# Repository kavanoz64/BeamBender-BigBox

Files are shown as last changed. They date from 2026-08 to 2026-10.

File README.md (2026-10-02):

# BeamBender BigBox

A digital scandoubler and HDMI output card for the **Amiga 4000**, with the **Amiga 2000 and 3000** supported as well.

The card plugs into the video slot, taps the digital RGB signals before they ever reach a DAC, and outputs clean **HDMI** with audio. No analogue stage, no capture artefacts, no flicker.

> This project is a big-box adaptation of [**jbilander/BeamBender**](https://github.com/jbilander/BeamBender), Jörgen Bilander's scandoubler for the Amiga 1200 (and 500). The original design's approach and much of its analogue and HDMI circuitry carry over directly. Jörgen has also provided hardware guidance throughout this redesign. All credit for the concept belongs upstream.

**Status: revision 0.3 hardware built and working on the Amiga 4000D, 4000T, 3000 and 2000 (ECS and OCS). Every Amiga monitor mode captured, including the A2024; interlaced modes deinterlaced motion-adaptively on both modules; integer and blended half-step scaling on both axes; with the Si5351C clock generator fitted, every output format on the i5 as well as the i9.** See [Status](#status) for detail.

---

## What's different from the A1200 original

The A1200 version clips onto the Lisa chip and connects to the main board via an FFC cable. Big-box Amigas expose the same signals on the video slot, so this version is a **single PCB with no cables**. It takes digital RGB, syncs and the pixel clock straight off the slot fingers, along with audio and power.

| | A1200 BeamBender | BeamBender BigBox |
|---|---|---|
| Signal source | Lisa chip (PLCC-84 clip) | Video slot |
| Boards | Two, joined by FFC | One |
| FPGA | Gowin GW1NR-9 (on-board) | Colorlight i5 or i9 module (SO-DIMM socket) |
| Video RAM | FPGA-internal | 8 MB 32-bit SDRAM on module |
| Audio in | 3.5 mm jack | Video slot, plus aux header and jack, mixed |
| Power | External connector | Slot |

---

## Hardware

**FPGA:** a [Colorlight i5 v7.0](https://github.com/wuxx/Colorlight-FPGA-Projects) module in a 200-pin DDR2 SO-DIMM socket (TE 1473149-4). The module carries a Lattice **ECP5 LFE5U-25F** (24k LUT), **8 MB of 32-bit SDRAM** for field storage, plus its own configuration flash and regulators.

Using a module rather than a bare FPGA is deliberate. The ECP5 only comes in BGA, and this design has a hard no-BGA-in-my-hands rule. A dead module is a socket swap, not a rework station. **SO-DIMM pin 41 is left unconnected** specifically so that the i5 and the i9 are interchangeable, since it is the one ball that differs between the two.

**The i9 (LFE5U-45F, 44k LUT, 4 PLLs) is the recommended module.** It is pin-compatible, it drops straight into the same socket, and the extra fabric and the two extra PLLs are doing real work: on a board without the clock generator below, the i9's PLLs are what clock the four VESA output formats, and it is the module with headroom for whatever comes next. Build with an i9 unless cost is the deciding factor.

The **i5 (LFE5U-25F)** remains fully supported as the cheaper option, with its own bitstream. On its own it covers the CEA formats plus 1920x1200, which is everything most people need for a television or a modern monitor; with the **Si5351C** fitted it has every format the i9 has. It is the fuller module, at 77 % of its logic now, so it is also the one that decides what fits.

**Clock generator:** an **Si5351C** (16-QFN) provides the pixel clocks the ECP5's PLLs cannot make from 27 MHz - 162 MHz for 1600x1200, 108 for 1280x1024, 65 for 1024x768 and 40 for 800x600 - on four inputs of the module. It was added to the revision 0.3 board as a rework and is part of the next revision. One firmware per module serves boards with and without it: at power-up the card measures the four pins, decides once which clocks are there, and offers each VESA format only while its clock is; an i9 falls back to its own PLL for a format whose clock is missing, an i5 drops to 1280x720. A one-output variant of the firmware (`-si1`) drives every VESA format from CLK0 alone, retuning the part over I²C at each format change, for a board that routes only that one output.

**Video out:** an **SiI9022A** HDMI transmitter fed 24-bit parallel RGB888 at up to 148.5 MHz. Bit-banged TMDS would not reach 1080p60 on a non-SERDES ECP5, so a real transmitter earns its place.

**Audio:** an **AK5720** 24-bit ADC digitises the audio and feeds I²S straight to the SiI9022A, bypassing the FPGA entirely. Ahead of it, an **OPA1692** inverting summing amplifier mixes the Amiga's line audio from the slot with an auxiliary input, so you can fold in another card's audio or an external source. The aux input appears on both an internal header and a switched 3.5 mm jack, where inserting a plug mechanically disconnects the header. The amplifier runs from the slot's +12 V through its own RC filter rather than the digital 5 V rail, and the ESD clamp on the external jack protects both entry points.

**HDMI +5 V:** HDMI requires the source to supply 5 V on pin 18, and plenty of DIY designs simply tie it to the board rail. That invites two failure modes: a shorted cable dragging your supply down, and cheap televisions pushing 5 V *back* into your system. A **TPS2553** load switch sits in that path instead, current-limited to a guaranteed minimum of 422 mA with reverse-current blocking, so neither can happen. Its enable and fault lines run to the FPGA, and the on-screen display reports the fault line.

**Level shifting:** two 74LVC16244 buffers translate the Amiga's 5 V logic to 3.3 V. The ECP5 is *not* 5 V tolerant, so these are mandatory rather than optional.

**Board:** 157.5 x 90 mm, 4-layer, with dedicated ground and 3V3 planes.

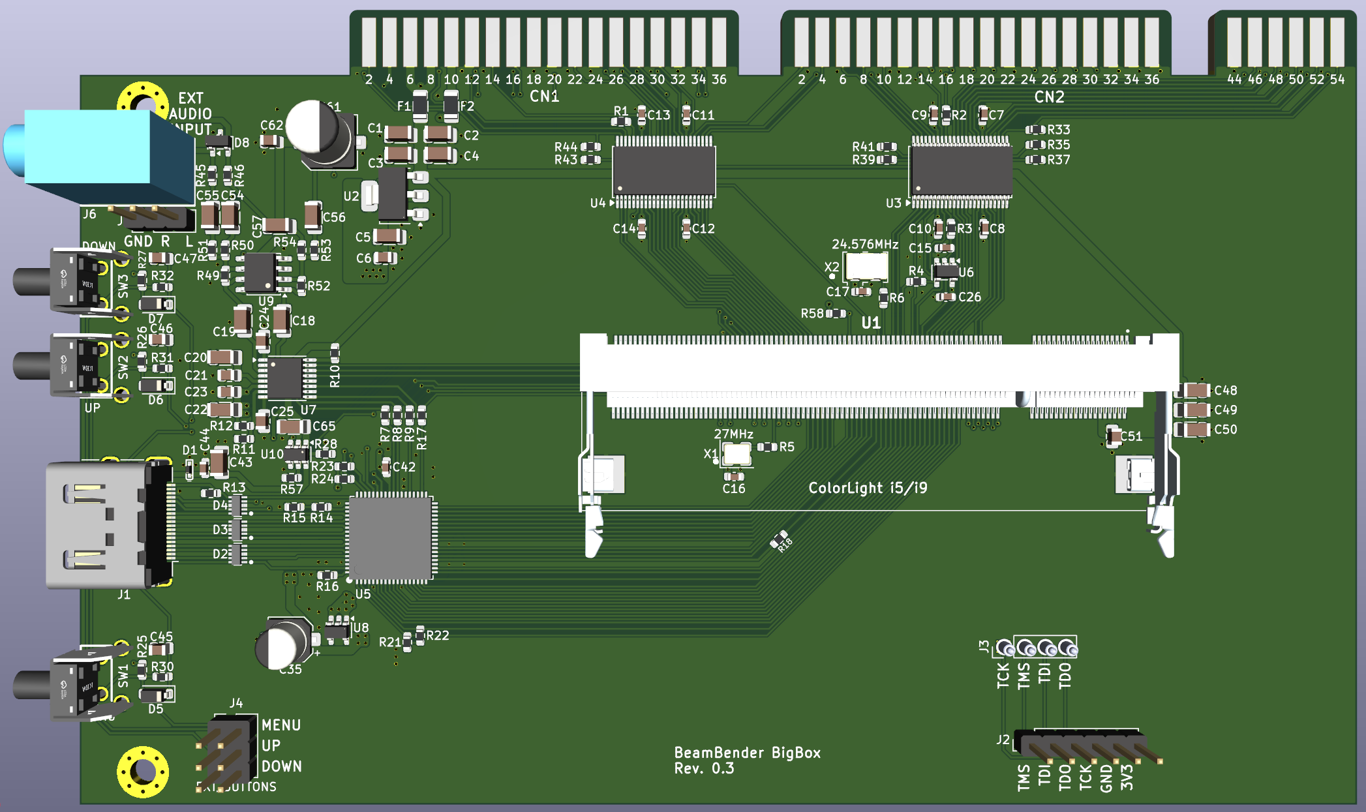
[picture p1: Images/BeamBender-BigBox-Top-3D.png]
PCB Top

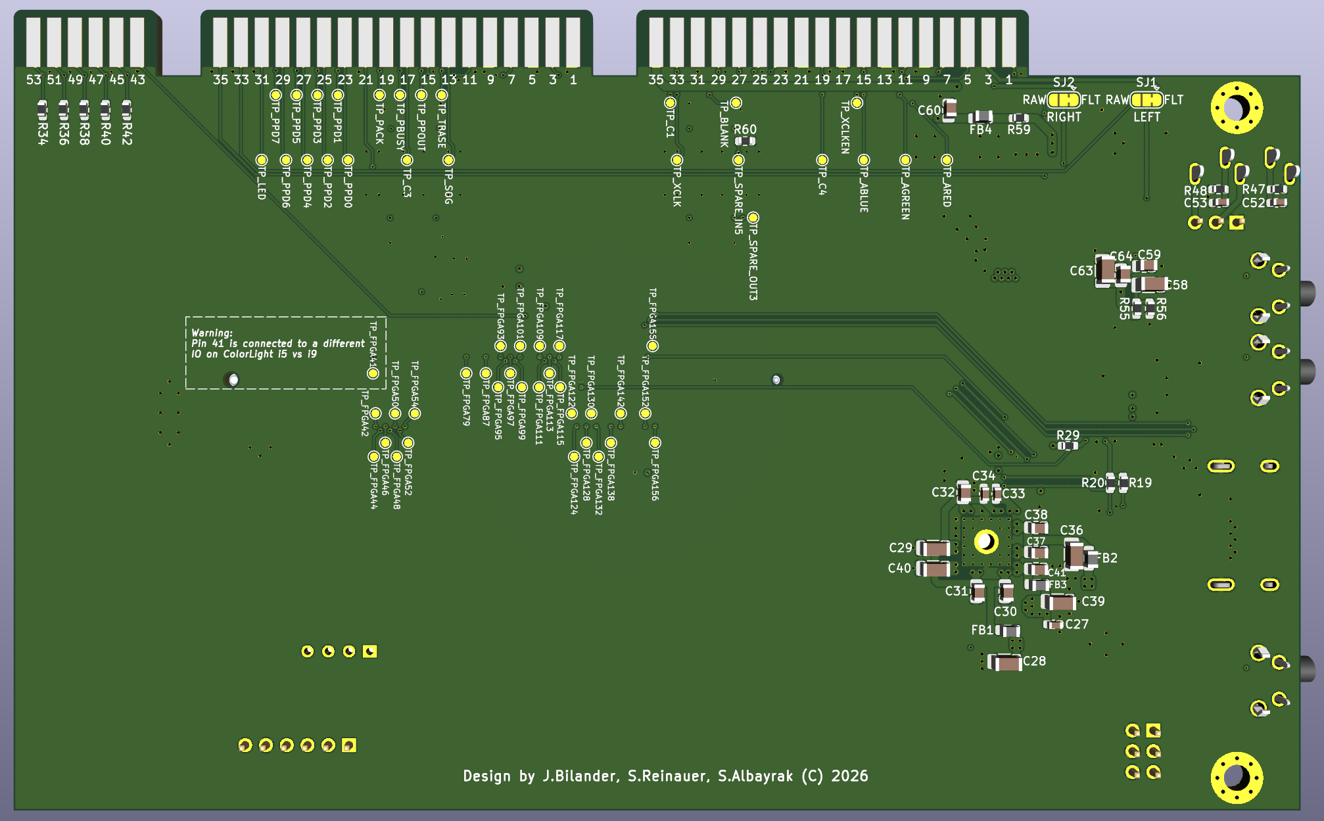
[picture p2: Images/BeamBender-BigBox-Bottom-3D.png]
PCB Bottom


### Where to buy the module

[Colorlight i5 + ext-board bundle on AliExpress](https://www.aliexpress.us/item/3256807602160285.html)

Buy the **module and the dev board together**. The BigBox card provides a JTAG header to program the module in place using an external programmer, but having the ext-board as well gives you a second, independent way to load and recover a bitstream, which may come handy.

---

## Clock architecture

Four clock inputs, on four dedicated ECP5 primary-clock pins.

| Clock | Source | ECP5 pin | PLL |
|---|---|---|---|
| **C28O**, 28.375 MHz PAL / 28.636 NTSC | Alice, via slot | 91 · `PCLKT2_1` | none, already the pixel clock |
| **VCDAC x2**, 14.19 MHz | Agnus/Alice CDAC, doubled on-board | 81 · `PCLKT3_1` | x2 to 28.375 MHz |
| **27 MHz** | on-board oscillator | 134 · `PCLKT7_1` | x5.5 to 148.5 MHz output |
| **24.576 MHz** | on-board oscillator | 89 · `PCLKT2_0` | none, audio MCLK reference |

Two details behind those choices:

**27 MHz is not arbitrary.** 148.5 MHz, the pixel clock for 1080p at both 50 and 60 Hz, is exactly 27 x 5.5, which the ECP5 PLL reaches cleanly. The module's own 25 MHz reference cannot produce it at any legal divider setting.

**The A2000 and A3000 have no 28 MHz clock on their video slots.** The fastest available is VCDAC at 7.09/7.16 MHz, which sits below the ECP5 PLL's 8 MHz input minimum. So an XOR gate and an RC delay double it to 14.19 MHz on-board, and the PLL takes it from there. Crude, cheap, and it adds no jitter of its own.

The two clocks that need PLLs sit on opposite die edges (banks 7 and 3), so each reaches its nearest PLL. That matters, because the LFE5U-25F only has two.

Both clock paths are confirmed on hardware: the A4000 runs from C28O, and the A3000 and A2000 run from the doubled VCDAC through the PLL. The card detects which is present and picks automatically, and the choice can be overridden from the menu. The Si5351C's four outputs come in on pins 81 (CLK0 162 MHz - the same pin as the doubled VCDAC on a board without the part; the firmware tells the two apart by frequency), 97 (CLK1 65), 142 (CLK2 108) and 138 (CLK3 40), and are measured by the firmware rather than assumed.

The card takes the slot's separate horizontal and vertical syncs. Composite sync alone is a build option (`--csync`), with the Sync Source row on the menu: it works on every mode including the AGA 31 kHz ones, but the separate syncs are the build that ships.

---

## Amiga 2000 / 3000 support

The pre-AGA video slot carries **12-bit color** (RGB444) rather than AGA's 24. Each nibble is replicated into both halves of an 8-bit channel, which is multiplication by 17. That maps 0 to 0 and 15 to 255 with no rounding error at any level.

Machine detection is passive. The AGA video slot extends the connector with pins 43 to 54, which don't exist at all on the A2000 and A3000. Pins 43 and 44 are ground, and 45 to 54 carry the extra color bits. A 10 kΩ pull-up on pin 43 therefore reads low on an A4000 and high everywhere else. The ten color lines on pins 45 to 54 get 100 kΩ pull-downs so their buffer inputs never float on a machine where those pins are absent.

The A3000 and the A2000, with OCS and with ECS chips, are all confirmed working.

---

## Programming

The module's JTAG pads aren't on the SO-DIMM edge, so four **spring-loaded pogo pins** contact them from below when the module is seated. A **1x6 JTAG header** runs in parallel for an external programmer. An FT232H or FT2232H dongle works directly with `openFPGALoader` or `ecpprog`.

Bitstreams can be loaded to SRAM for fast iteration, or written to the module's SPI flash through the same connection so the card boots on its own.

---

## Firmware

The gateware captures the Amiga's digital RGB into the module's SDRAM, scales it, and drives the SiI9022A.

**Prebuilt bitstreams are in [`Firmware/`](Firmware).** One file per module, named for the module and the firmware version. Load one and the card works; nothing else is needed. The AmigaOS tools that drive the card over its control link are in [`BBLink/`](BBLink), with their own README.

The firmware **sources are not published yet**. They will be, once the gateware reaches a maturity worth handing to other people. Until then the binaries are the deliverable, and the open items below are an honest account of what they do and do not do.

**Output formats.** One bitstream carries them all and the format is chosen from the menu:

| | i9 (recommended) | i5 | i5 with Si5351C |
|---|---|---|---|
| 720x576 / 720x480 | yes | yes | yes |
| 800x600 | yes | no | yes |
| 1024x768 | yes | no | yes |
| 1280x720 | yes | yes | yes |
| 1280x1024 | yes | no | yes |
| 1600x1200 | yes | no | yes |
| 1920x1080 | yes | yes | yes |
| 1920x1200 | yes | yes | yes |

All formats run at 50 or 60 Hz, following the Amiga automatically or forced from the menu. The format is chosen from a list rather than cycled, so the monitor re-locks once, on the one you asked for. A card with the Si5351C and no saved format comes up on 1280x1024, the format that shows a 512-line interlaced screen at exactly x2.

**Scaling.** The horizontal and vertical scales are chosen separately. **Auto** picks the largest integer that fits the format - PAL on 1080p is x2 by x3, a 512-line interlaced screen on 1280x1024 is x2 by x2 - and the picture is centred, with offsets from the menu. Forced scales add the **half steps, x1.5 to x5.5, blended**: each pair of source lines (or pixels) becomes 2k+1 rows (or columns) with the middle one the average of the two, so a PAL overscan screen of 288 lines fills 1008 of 1080p's rows at x3.5 with no uneven scanlines, and NTSC's 240 lines fill 1080 exactly at x4.5. Super-Hires is drawn on its own 1280 samples, never fewer columns than samples. Every number the menu shows is the screen's: a laced PAL screen reads 640x512, a Super-Hires one 1280 wide, the scale is per screen pixel and line, and the capture size times the scale is the output size. A format change, or a change of the screen being captured, puts both scales back on Auto. Scanline effect (two depths) and Super-Hires downsampling (sharp or soft, for the 720-wide formats) are settings; LoRes screens are stored one sample per pixel by default, so a 320-pixel screen reaches x6.

**Input.** Every mode the Amiga's monitor drivers produce: PAL and NTSC, Euro36, Euro72, Super72, DblPAL, DblNTSC and Multiscan, in LoRes, HiRes and Super-Hires, progressive and interlaced. The card recognises which monitor it is looking at from the line length and the lines per field, and keeps a settings set for each - and separate sets for the ECS and AGA chipsets, whose screens sit at different places on the line - so the geometry and sampling phase you set for one mode are there again the next time that mode appears. Picture position defaults come from a per-mode table of the Amiga's own placement (the A2000, A3000 and A4000 all measured), with manual Horizontal and Vertical Position on top. The Amiga's 28 input pins are registered in the pad cells, so the sampling edge does not move from build to build. Super-Hires is captured at full width, 1280 samples per line, one per output pixel rather than averaged down. Interlaced modes are **deinterlaced motion-adaptively, two samples at a time**: as each field is captured the card compares every pair of samples (one LoRes pixel, two HiRes ones) with the same pair of the previous field of the same parity, weaves the two fields wherever the picture is still and interpolates, from the neighbouring lines, only what moved - in either field - so a still Workbench stays as sharp as a weave, text keeps every one of its lines while the pointer passes over it, and a moving pointer or a scrolling window does not comb, however fast the pointer goes. Plain weave and bob are still there, chosen from the menu (Deinterlace = Adaptive, Weave or Bob), Display Info shows which of them the picture on screen actually has, and counts the changed pairs per field. Both modules do it, for every laced mode up to 768 samples a line, the 512-line DblPAL interlace included; Super-Hires interlace weaves plainly.

**The A2024** is supported as a 1024x1024 (PAL) or 1024x800 (NTSC) greyscale picture - BeamBender BigBox is the first Amiga scandoubler ever to display the A2024 modes. Commodore's monitor rebuilt its picture from four or six panels sent one per 15 kHz frame; the card does the same, assembling the panels in its frame buffer and showing the whole picture at 1:1 on 1280x1024 or 1080p. Both the 15Hz and 10Hz modes work, on PAL and NTSC.

**On-screen display.** A text menu on the card's three buttons covers output format and frequency, picture position, scale and offsets, capture width and height, scanline and picture effects, deinterlacing, menu size, position and background, the six OSD colours, source clock, sampling phase and calibration, plus Display Info, Monitor Info and Si5351 Info pages. Settings are written to the module's SPI flash and restored at power-up, and a record saved by an older firmware still loads.

**Monitor Info** reads the sink's EDID over the transmitter's DDC master and shows what the monitor actually claims to support, format by format, which is how you find out why a format is being refused.

**Hot plug.** The card watches the transmitter's hot-plug detect. Unplug the HDMI cable and plug it back in, or plug in a different monitor, and within about a second the transmitter is reconfigured for the new sink, the picture returns on its own, and the EDID is read again so Monitor Info describes the monitor that is there now. A cable that merely wobbles is ignored.

**Sampling calibration** sweeps the capture phase against a static picture and finds the centre of the eye. Needed because there is no fine phase shift available on the C28O path, and because the A3000's doubled clock has a narrower window than the A4000's.

**The Amiga control link** is three wires between test points already on the card - no new connector - giving a clocked full-duplex link to AmigaOS. The tools in [`BBLink/`](BBLink) drive it: `BBLink` (1.23) is a GadTools window with every setting, the live pages and the card's buttons; it backs the settings up to a human-readable text file and restores them, edits the OSD colours in a Palette-style editor, follows the sampling calibration through, and writes a report of what the card sees; `BBMode` tells the card which monitor the Amiga just switched to; `BBSurvey` walks every screen mode and logs what the card measured; `BBProbe` and `BBScreen` are the diagnostics; `BBLag` puts a field counter on the screen in digits big enough to film, for measuring the card's delay against the Amiga's own video. The wiring for the revision 0.3 board is in that README.

**Latency**, measured with BBLag and a 240 fps camera on a PAL HiRes screen: the picture on the card's HDMI monitor is between one and two fields (20 to 40 ms) behind the same picture on an analogue monitor, the HDMI monitor's own scaler included. One field of that is the frame buffer by design - the card shows the last field it has completely captured - and the rest drifts with the phase between the Amiga's field rate and the card's free-running output.

---

## Status

**The revision 0.3 board works.** Fabricated, assembled, and running on an **Amiga 4000D**, an **Amiga 4000T**, an **Amiga 3000** and an **Amiga 2000**. HDMI output, audio, the SDRAM frame buffer, the on-screen menu, settings in flash, every Amiga monitor mode including the A2024, the half-step scaling, the Si5351C clock generator (as a rework on this revision), and the Amiga link with its tools are all confirmed on hardware.

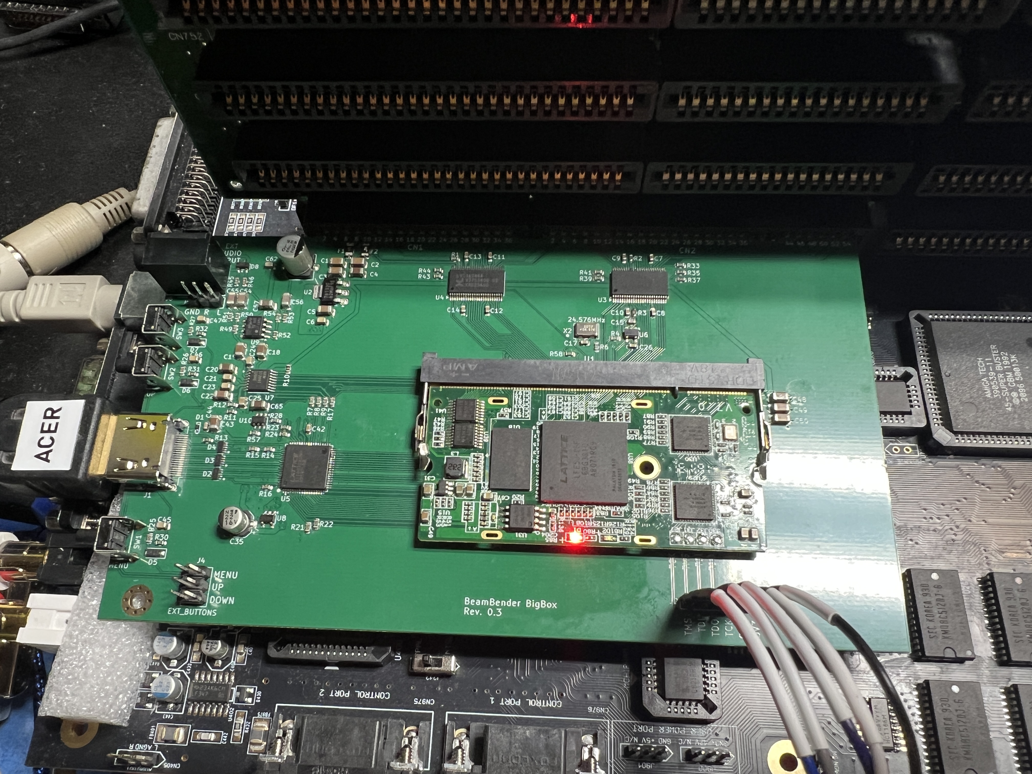
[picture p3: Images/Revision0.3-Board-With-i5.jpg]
Revision 0.3 board with an i5 module fitted


What is confirmed working:

- [x] First article fab and bring-up
- [x] HDMI output with audio, on multiple sinks
- [x] SDRAM frame buffer, full-width Super-Hires, interlace weave and bob
- [x] Motion-adaptive deinterlacing, on both modules
- [x] A4000D and A4000T (C28O path), A3000 and A2000 (doubled VCDAC path), OCS and ECS
- [x] Capture-phase calibration on real hardware, on both machine types
- [x] On-screen menu, settings saved to the module's SPI flash, one set per monitor mode
- [x] EDID read-back from the sink, shown format by format on Monitor Info
- [x] Hot plug: a replugged or swapped monitor comes back on its own, EDID re-read
- [x] Amiga control link and the AmigaOS tools: BBLink, BBMode, BBSurvey, BBProbe, BBScreen, BBLag
- [x] Latency measured: one to two fields to the HDMI monitor
- [x] i9 module support, with 800x600, 1024x768, 1280x1024 and 1600x1200
- [x] 1920x1200 on both modules
- [x] All the doubled-scan and productivity modes: DblPAL, DblNTSC, Super72, Euro36, Euro72, Multiscan
- [x] The A2024, 15Hz and 10Hz, PAL and NTSC, reassembled to the full 1024-line picture
- [x] The Si5351C clock generator: every output format on the i5, one firmware per module with or without the part
- [x] Blended half-step scaling, x1.5 to x5.5, both axes; Super-Hires on its own samples; the menu in screen pixels and lines
- [x] Composite sync on every mode, as a build option
- [x] OSD colours, settings backup and restore, a report, from BBLink

What is still open:

- [ ] Measure actual current on the 5 V and 3.3 V rails

### Next steps

**Hardware.** Measure the rails. The next board revision carries the Si5351C on the board and folds the Amiga link's three jumpers in as traces; one FPGA pin (the former BLANK input) is free.

**Firmware.** Publishing the sources.

---

## Building one

The Gerbers have not been published, but can be generated from the KiCad files here. The PCB is designed around **JLCPCB** fabrication and assembly, with part selection biased toward their basic library. The Colorlight module and the pogo pins are hand-fitted afterwards.

Fit an **i9** module unless cost rules it out. A finished board needs no toolchain: take the matching bitstream from [`Firmware/`](Firmware) and load it.

---

## Credits

- **[Jörgen Bilander](https://github.com/jbilander)**, original BeamBender design, and ongoing guidance on this adaptation
- **[Salih Albayrak (aka Kavanoz)](https://github.com/kavanoz64)**, hardware design and implementation for BigBox
- **[Stefan Reinauer](https://github.com/reinauer)**, FPGA programming
- **Claude AI** (Anthropic), design review, component selection, gateware and documentation
- **[wuxx](https://github.com/wuxx/Colorlight-FPGA-Projects)** and the Colorlight reverse-engineering community, for module pinouts and documentation that the vendor doesn't publish

## License

Please check the licensing of the upstream [BeamBender](https://github.com/jbilander/BeamBender) project before redistributing derived work.

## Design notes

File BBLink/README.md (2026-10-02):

# BeamBender BigBox — the Amiga tools

Five programs that talk to a BeamBender BigBox card from the Amiga it is
plugged into. Everything the card can do from its own on-screen display (OSD)
and its three buttons, you can do from here instead, with a keyboard and a
mouse and somewhere to read the numbers.

| | what it is for |
|---|---|
| [**BBLink**](#bblink) | the window. Every setting, the live pages, the card's buttons, and your settings backed up to a file. This is the one you will use. |
| [**BBMode**](#bbmode) | runs in the background and tells the card which monitor mode the Amiga just switched to. No longer needed - the card detects every mode by itself, reliably - but still here for anyone who wants the card told rather than left to measure. |
| [**BBSurvey**](#bbsurvey) | opens every screen mode the Amiga has, one after another, and logs what the card measures on each. |
| [**BBProbe**](#bbprobe) | for when nothing answers. It prints the raw bytes on the wire and squares up one line at a time so a meter or a scope can find the break. It also reads raw lines of the picture. |
| [**BBScreen**](#bbscreen) | opens one screen mode with a test pattern and runs a command in front of it. |
| [**BBLag**](#bblag) | a field counter in digits big enough to film, for measuring the card's lag against the Amiga's own video. |
| [**BBKeyCon**](#bbkeycon) | a commodity: Left Shift + Left Alt + a key presses the card's buttons and brings up its pages, from any screen. |

They share one link and take it only for the length of a single exchange, so
they can all run at the same time.

---

## Before anything will work

**The three link wires have to be fitted to the card.** On the revision 0.3
board they are three short wires and one resistor between test points that
are already there, plus one resistor to remove. See
[Wiring the link on a revision 0.3 board](#wiring-the-link-on-a-revision-03-board)
below. Without them the tools will say nobody answered, and they will be
right.

**Firmware and tool versions belong together.** BBLink shows the card's
firmware version in its title bar and its own under **About BBLink...**;
when the two firmware numbers differ, rebuild the tools against the
firmware you are running (see the About section below). A page or a row
the running firmware does not have is simply missing from the tool rather
than opened in the wrong place.

**Unplug any printer from the parallel port.** A printer holding the BUSY
line high blocks the card's side of the conversation. Nothing is damaged, it
simply cannot be read.

**AmigaOS 2.0 or later.** Nothing to install: everything these use is in ROM,
and `misc.resource`, which hands out the parallel port, is older than that.

## Installing

Unpack `bblink.lha` wherever you like — `SYS:Tools` is a reasonable home.

```
lha x bblink.lha
```

LhA keeps the protection bits, so the executable flag survives the trip and
none of the five needs `Protect +e`. The archive holds the five executables
and nothing else; this guide sits beside it.

## Wiring the link on a revision 0.3 board

The link is three signals from the Amiga's parallel port, which reach the
video slot on CN622: **PPOUT** (the clock, Amiga to card), **PSEL** (data,
Amiga to card) and **PBUSY** (data, card to Amiga). PSEL is already routed
on the board. The other two are made with wire on the test points, as the
photo shows:

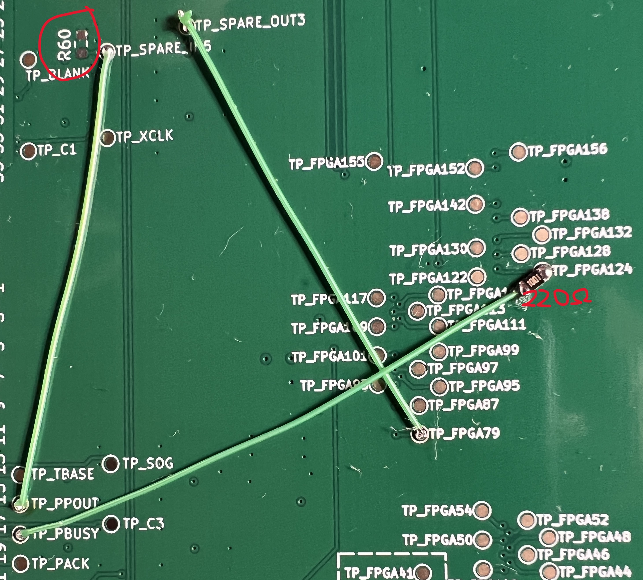
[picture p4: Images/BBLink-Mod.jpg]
The link wiring on a revision 0.3 board


1. **TP_PPOUT to TP_SPARE_IN5** - a wire. PPOUT goes in through a spare
   channel of the 5 V to 3.3 V buffer.
2. **TP_SPARE_OUT3 to TP_FPGA79** - a wire. The buffered PPOUT reaches the
   FPGA.
3. **TP_FPGA124 to TP_PBUSY through a 220 Ω resistor** (200 Ω is fine too).
   The card's reply. The FPGA only ever pulls this line low; the Amiga's
   own pull-up makes the high, so no 3.3 V is ever driven onto the 5 V net.
4. **Remove R60**, the 0 Ω link circled in the photo, which ties SPARE_IN5
   to ground. Leaving it fitted holds the clock input low and nothing will
   ever answer.

Four solder joints and one part lifted. Nothing else on the board changes,
and the card works exactly as before with the wires fitted and no tool
running.

---

# BBLink

Double-click it, or run it from a Shell. A window opens on the default public
screen with the card's firmware version in the title bar:

```
BBLink 1.23  2026-09-30.07 i9
```

**That version is the CARD's**, read over the link. The tool's own is under
**About BBLink...** in the Project menu (right mouse button):

```
BBLink 1.23  for firmware 2026-09-30.07
Oct  1 2026  18:30:00

Card: 2026-09-30.06 i9
```

If those two firmware numbers differ, the tool was built against tables from
another firmware. It still runs, but a setting that moved between those two
versions will be in the wrong place, so rebuild it against the firmware you
are running.

The second line is when that binary was compiled, and it is the one to look
at when a rebuild does not seem to have taken. It is fixed at compile time,
so it cannot be stale, and it settles at a glance whether the program in
front of you is the one you just built or an older copy still sitting on
the Amiga. The About BUTTON on the main screen is the card's own About page,
which is about the card.

## The main screen

Top to bottom:

- **Output Format**, **Output Frequency**, **Status Lines** and **Menu
  Position**, the settings you change most often. Output Format drops a
  list under its button - one row a format, the current one marked `>`:
  click the format you want and the card switches
  to it, or click anywhere else to leave it. The list is in ascending
  order and shows 720x480 or 720x576 according to the frequency the card
  is on. The other three are cycle gadgets: a click steps to the next
  value. Status Lines turns the two information lines at the top and
  bottom of the picture off and on; Menu Position moves the card's menu
  block through the centre and the four corners of the picture, so it can
  be put where it covers nothing you are looking at.
- **Display Info** | **Input Sampling**
- **Monitor Info** | **Output Geometry**
- **Settings** | **Load Settings** | **Save Settings**
- **Reset to Defaults** | **Report** | **About**
- **Refresh Rate**, with its own gadget: `Off`, `1 second`, `2 seconds`,
  `5 seconds`.
- **MENU** | **MENU Long**
- **UP** | **UP Long**
- **DOWN** | **DOWN Long**

A button that opens another page takes you there; **Go Back <<** at the
bottom of each page brings you home. The line along the bottom of the window
is where the tool tells you what just happened.

## Output Geometry

Five rows, one axis at a time: **Horizontal Offset** and **Horizontal
Scale**, then **Vertical Offset** and **Vertical Scale**. The offsets move
the finished picture inside the frame your monitor is given; the scales
decide how big it is.

Each scale is `Auto` or `x1` to `x6` in half steps (`x1.5`, `x2.5` ... the
half step draws every second column or row as the blend of its two
neighbours): how many output columns each screen pixel gets, or how many
output rows each screen line. `Auto` picks what the card has always picked
- horizontally the multiplier that fills the 4:3 box, vertically the largest
that fits the active area - and is right almost always. Force one when you want something else: smaller, to make
room for **overscan** (capture more with Capture Width or Capture Height and
it grows into the space instead of pushing the scale down a step), or
larger, to fill a 16:9 screen edge to edge with a picture that was never
that shape.

**A scale that does not fit is skipped.** The card's own cycle only stops on
the scales its current output format has room for, given the size of the
capture: 320 columns on 1280x1024 offer `Auto, x1 ... x4` and skip anything
above. From here the gadget still lists every value, and one the card
cannot use is refused with a message rather than taken. Display Info's
`Scale` row (`2x4` is horizontal x vertical, `1.5x3.5` with half steps)
shows what is actually in force, and the rows read the same: a forced scale
the card cannot use on the screen it is looking at reads `Auto` until that
screen is back.

**Every number is the screen's.** Capture Size is the width in the screen's
own pixels (640 HiRes, 1280 Super-Hires) and the height in its lines (512
for an interlaced PAL screen, 1024 for the A2024), the Capture Height row
counts the same lines (stepping by two on an interlaced screen), and the
scale is per screen pixel and per screen line, so Capture Size times Scale
is what goes to the output. On a Super-Hires screen every sample is drawn,
so the horizontal cycle offers `x1, x1.5, x2 ...` and never fewer columns
than samples; the one fraction below 1, `x0.5`, appears only where 1280
samples have to fit 640 columns (the SD formats).

The offsets and scales are saved per output format and frequency; the
positions, sampling phase and capture size per monitor mode. Changing the
output format puts both scales of the new format back on `Auto` ("no
surprises"); the flash keeps what was saved until the next Save Settings.

## Changing a setting

Every setting the card has is on one of the pages, one gadget per setting.
Settings that pick from a few values get a cycle gadget, Output Format a
drop-down list, and settings that are numbers get `[-] value [+]`.

A setting the card has greyed out in the current output format is **ghosted**
here too. A gadget you cannot click says the same thing as `N/A` and cannot
be clicked by mistake.

When you change something, the card's own menu appears on the monitor and
moves for a few milliseconds while the card walks to that setting, then it is
put back exactly where it was. That flicker is normal and is the card being
driven, not a fault.

**Nothing is kept until you press Save Settings.** Everything you change is
live immediately and lost at the next power cycle unless you save it.

## The live pages

**Display Info**, **Monitor Info** and **About** are the card's own pages,
row for row. Each is a screen of its own with a **Go Back <<** at the bottom,
so there is nothing else on screen while you are reading one.

A page is read the moment you open it, and then re-read on the timer you set
with **Refresh Rate** back on the main screen. Set that to `Off` and a page is
read once, when you open it, and then left alone until you leave and come
back.

Display Info carries one row the card cannot draw, because it is about the
**Amiga's** end of the link: how many exchanges have been retried and how
many were given up on. A link that works but retries constantly is a wiring
problem, and this is where you see it.

## The card's buttons

**MENU**, **UP** and **DOWN**, and a long press of each. Six gadgets rather
than three that you hold down, because a window cannot time a click reliably
and guessing at it would be worse than saying plainly what each one does.

## Load, Save, Defaults, Calibrate

- **Save Settings** writes everything to the card's flash. It survives a power
  cycle and a fresh bitstream, because it lives in a corner of the flash that
  programming the card does not touch.
- **Load Settings** reads the flash back and throws away everything changed
  since the last save. The row says `Loaded`, or `Failed` when there is no
  usable record in the flash - after the rescue erase, say - and in that case
  nothing at all is changed.
- **Reset to Defaults** puts every setting back and does **not** save. Press
  Save Settings afterwards if that is what you want kept.
- **Calibrate Sampling**, on the Input Sampling page, sweeps the sampling
  phase on the card (a few seconds, the card's own screen showing the
  scores) and then waits for a verdict. From BBLink 1.22 the tool follows
  it: while the card waits, the Calibrate Sampling button becomes
  **Accept | Cancel**, every other row and button on the page is greyed,
  and the **-** and **+** of Sampling Phase walk the card's selection
  through the twenty measured points with the picture showing each.
  Accept keeps the phase shown, Cancel puts back the one in use before the
  sweep; the page is restored either way, and also when the verdict is
  given with the card's own buttons.

## Report

**Report** writes `RAM:BBLink.txt`: the firmware version, every page, every
setting and the link's retry counters. This is the one to press before
describing a problem to anybody.

## Backup and Restore Settings

Both are in the **Project** menu, on the right mouse button, with **OSD
Colours**, **About BBLink** and **Quit** under them. Each opens the standard file requester (asl.library;
without it the file is `PROGDIR:BeamBender.settings` and the status line
says so).

**Backup Settings...** reads every setting off the card and writes it as a
text file you can read and edit:

```
# BeamBender BigBox settings
# From a BigBox i9 running 2026-09-30.07, by BBLink 1.23
# The live settings: what Save Settings would have written.

[General]
Output Format = 1920x1080
Output Frequency = Auto
Status Lines = Shown
Menu Position = Center
Deinterlace = Adaptive
...

[Input PAL]
Horizontal Position = 413
Vertical Position = 40
Vertical Half Line = No
Sampling Phase = 102
Pixel Phase = 0
Capture Width = 640
Capture Height = 256   # lines per field: an interlaced screen shows twice this

[Output 1920x1080 50Hz]
Horizontal Offset = 0
Vertical Offset = 0
Horizontal Scale = Auto
Vertical Scale = Auto
```

The scales are under the OUTPUT they belong to: a scale is an answer to
how big the picture should be on a given output, and the card keeps one
pair per output format alongside the offsets. The file keeps each SET'S
own units, since one set serves both the progressive and the interlaced
screens of its standard: `Capture Height` is lines per field (256 where
the window shows 512 on an interlaced screen), and `Horizontal Scale` the
value on the 640-column grid (x2 where a Super-Hires screen shows x1). The
report and the window show the screen's numbers. BBLink 1.23 or later is
needed for a file with half-step scales: 1.22 wrote them as `Auto`.

The words are the card's own: what a row shows on the monitor is what the
file says. It is the **live** settings that are written, including anything
changed and not yet saved; if you want exactly what is in the flash, press
Load Settings first.

**Restore Settings...** reads such a file and sends it to the card. Names are
matched, not positions, so a file from an older firmware puts back everything
it has and leaves the rest as the card has it; a name the card does not know,
or a value it cannot take, is counted and shown before anything is sent, and
you can stop there. The card checks the whole record before it applies any
of it, so a file it will not accept changes nothing. Afterwards the tool
reads the settings back and says whether they match - and then asks whether
to **Save Settings**, because a restore lives only until the next power
cycle until you do.

This is also the way to carry settings across a firmware update that changes
the record format: back up before, restore after, and the positions and
sampling phases you spent an evening on are back without a button pressed.

## OSD Colours

**OSD Colours...** in the Project menu (BBLink 1.21, firmware 2026-09-28.02
or later; spelt "Colors" unless the OS's locale says the United Kingdom)
is a small Palette Prefs: a list of the six colours the card
draws its menu in - the **Bands** (the bars at the top and bottom of the
block), the **Highlight** bar under the selected row, **Labels**,
**Values**, the **Shadow** under the text, and the menu **Background** (the
colour the picture is dimmed towards at the Menu Background levels
between 0 and 100 %, and the solid colour at 100 %) - with a swatch of
the selected one under the list, Red / Green / Blue sliders with their
numbers, the hex, and on Workbench 3.0 or later the colour wheel with its
brightness slider (the sliders alone on 2.x). Text on the highlight bar
is drawn in the shadow's colour; the alert red stays red. **Apply** sends
the six to the card, which draws them at once; **Save** applies and then
writes the card's flash, as Save Settings does; **Defaults** puts the
built-in colours back in the list (FFD000, FFD000, B0B0B0, FFFFFF,
000000, 000000) for the next Apply; **Cancel** closes the window. The
colours are part of the settings record, so a backup carries them under
`[OSD Colours]` and a restore puts them back. **Quit** in the same menu
closes the tool, as the window's close gadget does.

### From a Shell

Both work without the window, for scripts and for a backup before every
firmware update:

```
BBLink BACKUP <file>            the live settings to a file
BBLink RESTORE <file>           a file to the card; not saved to the flash
BBLink RESTOREANDSAVE <file>    a file to the card AND into its flash
BBLink ... QUIET                say nothing; the return code is the answer
```

The keywords are AmigaDOS ones, so `BBLink backup SYS:bb.settings` and
`BBLink BACKUP=SYS:bb.settings` are the same command. A restore from the
shell has nobody to ask, so a name the card does not know or a value it
cannot take is reported and the rest is sent. The return code is 0 when
everything was done, 5 (WARN) when the restore went in but something in the
file was skipped, and 20 (FAIL) when nothing was changed: the file could not
be read, the card refused the record, or the save did not verify. A script
can test it:

```
BBLink RESTOREANDSAVE SYS:bb.settings QUIET
IF WARN
  Echo "Some of the file was not restored"
ENDIF
```

---

# BBMode

**Run it from a Shell**, or put it in your `S:User-Startup`.

```
BBMode              follow the front screen until Ctrl-C
BBMode QUIET        the same, silently
BBMode ONCE         set the card to match the screen now, then exit
BBMode KEEP         do not put the card back on Auto on the way out
BBMode DELAY=n      how often to look, in ticks (default 25, half a second)
```

It prints one line every time the screen mode changes and nothing at all in
between:

```
PAL:High Res             -> PAL        ok
DBLPAL:High Res Laced    -> DBLPAL     ok
SUPER72:High Res         -> SUPER72    ok
```

`ok` means the card **read back** in that mode, not merely that a message was
sent.

## What it is for

**You do not need it.** The card works out which monitor it is looking at
from the line length and the lines per field, and the A2024 from its
colour signature, and it does so reliably for every mode the Amiga has;
that is what **Auto** does, and Auto is the right setting. BBMode exists
for the one thing a measurement cannot do: the Amiga chose the mode, so it
knows which monitor it is about to produce before the first line is drawn,
and BBMode passes that on, so the card need not wait the few frames the
measurement takes to settle.

It changes nothing else: not the sampling phase, not the positions, not the
capture height. Those are per-monitor settings the card already keeps and
reloads by itself. This only says **which monitor**.

## In your startup

```
Run >NIL: <NIL: BBMode QUIET
```

`Break <task>` stops it, exactly as Ctrl-C does from a Shell. Started from
Workbench it goes quiet by itself, since there is nowhere for it to print.

## On the way out it puts the card back on Auto

Unless you give it `KEEP`. A card left pinned by a program that is no longer
running will sample the next 15 kHz mode with 29 kHz settings, and nobody ever
connects that to something they stopped an hour ago.

## If a mode prints "monitor not in the table"

```
FOO:Something            -> Auto       (monitor not in the table)
```

The card is left on Auto, which is exactly where it would have been without
BBMode, so nothing is worse. Send that line on and the monitor can be added.
BBMode matches on the monitor name, the part before the colon, and knows
PAL, NTSC, EURO (36Hz and 72Hz told apart by the mode name), A2024 (PAL or
NTSC by the standard the machine booted in), SUPER72, DBLPAL, DBLNTSC,
MULTISCAN, VGA and PRODUCTIVITY (the last two as Multiscan). A plain mode
with no monitor name follows the boot standard.

---

# BBSurvey

**Run it from a Shell, in the drawer the log should land in.** It opens
every screen mode in the display database one after another, waits for the
card to settle on each, and writes one line per mode to `BBSurvey.log` in
the current directory: what the Amiga calls the mode and what the card
measured on it. It is how the table of monitor modes inside the card was
built, from measurement rather than from memory, and it is the quickest
way to show that every mode a machine has is recognised.

```
BBSurvey                 every mode, log to BBSurvey.log here
BBSurvey FILE=name       the log goes there instead
BBSurvey MONITOR=name    only that monitor's modes (PAL, DBLPAL, SUPER72 ...)
BBSurvey DEPTH=n         screen depth, default 2 (four colours)
BBSurvey WAIT=n          give a mode up after n seconds (default 5)
BBSurvey ALL             include the VGAONLY monitor and the HAM, EHB and
                         dual-playfield variants, which are the same timing
                         under another name
BBSurvey QUIET           nothing on the console; the log says it all
```

What happens, in order. It reads the card's live settings and keeps a copy
in memory and in `BBSurvey.settings` beside the log (a BBLink settings file,
so it can be restored by hand if the run is broken off). Then, for each
mode that the OS says is available, it opens a screen of the mode's nominal
size, paints it in bands of white, red and blue plus a band of single-pixel
stripes (the LoRes detector needs neighbouring pixels that differ; flat
colour reads as LoRes on every mode) with the mode's name at the top, and
polls the card until what it measures has stopped changing: the
flywheel re-locks, the standard detector settles and the monitor comes back
over a few seconds, exactly as a ScreenMode prefs switch does. Five reads a
fifth of a second apart that all agree, after at least a second, count as
settled; `WAIT` seconds is the give-up and the line is marked
`(NOT SETTLED)`. Each line ends with `SETTLE n.ns`, the time after the
screen opened at which the card's reading last changed, which is the
card's own settling time without the second of caution the five reads add
(so a mode that settles at 0.4s costs the tool about 1.4s). The line is
written, the screen closed, the next opened.
At the end the settings are read back and, if anything differs from the
copy, the copy is put back over the link. Ctrl-C stops the walk early and
still restores.

A line looks like this (one line in the file; wrapped here):

```
00021000  PAL:High Res                   640x256  PROG PAL    4  |
  PAL HIRES PROG         Locked (green)  LINES 312  LEN 1816  15.62 kHz
  RGB FFFFFF  PAIRS 0 0  UND 0  OVR 0  CAP 640x256  28M H+V Sync
  SET PAL  MODE Auto  SETTLE 0.6s
```

Left of the bar is the Amiga's side: the ModeID, the name, the nominal size,
whether the OS calls it interlaced and PAL, the maximum depth. Right of it is
the card's: the Input row as the OSD shows it, the lock state, lines per
field, line length in capture clocks, line rate, the colour bits that ever
lit (an A2024 mode always reads `888899` because its four one-bit planes
never light more, which is why A2024 screens are opened with all four
whatever `DEPTH` says, falling back to fewer if the chip RAM will not take
half a megabyte), the pair counters, under/over, the capture size the set
gave, the clock and sync source, the set in use and the Input Mode setting.

The header also records the tool's own version, the standard the Amiga
booted in (the jumper, from graphics.library's DisplayFlags) and the
capture clock the card measures: 28375 kHz is the PAL crystal, 28636 the
NTSC one, so the crystal-and-jumper combinations need no renaming by hand.

The output format is left alone: everything on the card's side of the line
is measured on the input, and none of it depends on what the HDMI side is
doing. The header of the log records the output format, the hardware and
the LoRes Capture setting anyway. Nothing is changed on the card by the
survey itself; if `BBMode` is running it goes on pinning the class, and the
`MODE` column shows it.

Only the monitors whose drivers are in `DEVS:Monitors` are in the display
database, so put the ones to be surveyed there first (PAL, NTSC, Euro36,
Euro72, Super72, DblPAL, DblNTSC, Multiscan, A2024) and reboot. A mode the
OS lists but cannot open is logged as `not available`.

---

# BBProbe

**Run it from a Shell, not from Workbench**, or its output goes nowhere.

```
BBProbe              ping in a loop, printing every reply, until Ctrl-C
BBProbe ONCE         one exchange, printed, exit
BBProbe TOGGLE       square-wave the CLOCK line until Ctrl-C
BBProbe TOGGLEDATA   square-wave the DATA line until Ctrl-C
BBProbe RETURN       read the return line twice a second and print it
BBProbe HAMMER       exchanges back to back, nothing printed
BBProbe RAW aa bb cc dd ee    send five bytes exactly as given
BBProbe LINE n [TO m] [COUNT k] [SHIFT s] [PHASE p] [FILE name]
                     the raw pixels of input line n
```

`LINE` is the odd one out: it looks at the picture, not the wire. The card
keeps one line of what the Amiga is sending, in the card's own capture
clocks, and this reads it back: 1024 entries of `R G B` (red and green as
their top four bits, blue as all eight), one entry every `2^SHIFT` clocks
(1, the HiRes pixel rate, unless given), for line `n` counted the way
Vertical Position counts (lines after the vertical sync). `TO m` walks a
range of lines, `COUNT k` takes the same line from k frames in a row, and
`FILE` writes it out instead of printing it. About 0.4 s a line. It exists
for the A2024, whose frames say which quarter of the picture they carry in
a line of coloured marks near the top - which is how the A2024 support was
measured.

This exists because "no BeamBender answered on the parallel port" is the same
sentence whether the clock never left the Amiga, the buffer never passed it
on, the card never answered, or the card answered and the bits were wrong. The
five bytes that actually came back tell those apart in one look:

| what you see | what it means |
|---|---|
| `FF FF FF FF FF` | nothing is driving the return line at all |
| `00 00 00 00 00` | the return line is stuck low |
| status bit 7 clear | something answered, but it was not the card |
| `ok` with a value | the transport is working |

`TOGGLE` is the one to put a scope on. BBLink sends a few hundred
microseconds of traffic and stops, which is nothing you can trigger on by
hand; this holds one line square for as long as you like, so it can be
followed from the test point on the motherboard all the way to the card's
field-programmable gate array (FPGA) pin. `HAMMER` does the same job for a
plain multimeter, by keeping the return line busy about half the time.

---

# BBScreen

**Run it from a Shell.** It opens one screen mode with a test pattern on
it, runs a command while the screen is in front, closes the screen and
gives you back whatever was there before:

```
BBScreen MODE "A2024:15Hz"                  the pattern for 10 seconds
BBScreen MODE "A2024:15Hz" WAIT 0           ...until Ctrl-C
BBScreen MODE 49000 CMD "BBProbe LINE 18"   run a command with the screen up
```

MODE is the start of a mode's name as ScreenMode prefs shows it, either
case, or the mode's hex number. The pattern is rulers every 64 pixels, a
grey ramp and single-line stripes across the top, a white border, and one
to four white blocks in the four quarters of the screen so that a line read
back over the link says which quarter it came from by counting. An A2024
mode opens four planes deep, which BBSurvey found is what makes the A2024
signal complete; `DEPTH n` overrides.

With `CMD "BBProbe LINE n FILE name"` it captures a line of a mode that
only exists while a screen of that mode is open, which is what it is for.

---

# BBLag

**Run it from a Shell.** It measures nothing itself: it puts a counter on
the screen that advances every field, in digits 64 pixels tall, so that a
camera can film a monitor on the Amiga's own video and the card's monitor
in the same shot. The two numbers in one frame of that video differ by the
card's lag, in fields (20 ms each on PAL, 16.67 on NTSC).

```
BBLag                        PAL or NTSC High Res, until Ctrl-C
BBLag MODE "PAL:High Res"    a mode by name or hex number, as BBScreen
BBLag WAIT 30                stop after 30 seconds
```

The screen shows, top to bottom: a bar that steps right every field and
wraps every 32 (readable through motion blur when the digits are not); the
count's low eight bits as eight squares; the field count; the same count
in milliseconds. Everything is drawn in the first lines after the vertical
blank, so each field carries one complete number.

Film at 60 frames a second to read the lag to a field, or in a phone's
slow-motion mode (120 or 240) to read it finer - the CRT's beam is visible
as a bright band then, and the lag is the time between the same row of the
same number on the two screens. Take the difference that repeats across
ten or more frames: any camera frame that straddles a vertical blank
catches one screen mid-change.

Interlaced modes advance the count every field too, but each field
carries half the rows, so the digits read as two numbers interleaved:
use a non-interlaced mode unless the interlaced path is the one being
measured, and then read the bar and the squares.

---

# BBKeyCon

A commodity that puts the card's three buttons, and its pages, on the
keyboard - so the menu can be opened, walked and closed while a game or a
demo has the screen, without reaching into the machine or leaving for
BBLink's window. Start it once:

```
Run >NIL: <NIL: BBKeyCon QUIET       from the startup-sequence
BBKeyCon                             from a Shell, until Ctrl-C
BBKeyCon MODS "lshift lcommand"      other modifier keys (default lshift lalt)
BBKeyCon TEST                        the link stays closed: each key that
                                     matches is printed, nothing reaches the card
BBKeyCon VERBOSE                     as normal, and every press is printed
```

**Try `BBKeyCon TEST` first** on a machine it has not run on: it lists the
nine key descriptions the OS accepted, then prints a line for every chord
that matches, and the card is never touched. If a chord prints nothing, the
keymap or the `MODS` pair is the thing to look at, not the link.

Hold **Left Shift and Left Alt**, then press:

| key | does |
|---|---|
| Esc | opens the menu, or closes whatever is open (menu, submenu, page) |
| Cursor Right | the MENU button: enter the row, accept a value (with the menu closed, opens it) |
| Cursor Up | the UP button: previous row, value up (repeats while held) |
| Cursor Down | the DOWN button: next row, value down (repeats while held) |
| Cursor Left | a long MENU press: abandons an Output Format choice; with the menu closed, toggles the status lines |
| D | the Display Info page |
| M | the Monitor Info page |
| S | the Settings submenu |
| A | the About page |

From a page, Esc closes the menu and Right, Up or Down go back to the
menu, as any button does at the card. The four cursor keys are the whole
of the menu: Up and Down walk it, Right goes in, Left backs out. The keystrokes never reach a window.
It shows in Exchange as "BBKeyCon", where it can be disabled or removed.

Left Shift + Left Alt is the pair no part of the OS uses: the Left Amiga
key with the cursor keys is Intuition's mouse emulation (and with Left Alt,
the mouse button), Left Amiga + N and M flip screens, Right Amiga is every
program's menu shortcut. `MODS` takes any two of `lshift`, `lalt` and
`lcommand` (Left Amiga) if a program of yours wants the default pair.

It holds the link open while it runs, which takes the parallel port only for
the length of a frame, so BBLink and BBMode run beside it. A press that
seems to do nothing was a frame lost to the link; press again.

Two guards, after version 1.0 took the whole input stream with it on the
bench (the menu toggling on every mouse movement and timer tick, keyboard
and mouse dead until a reset): every key filter is checked for having
taken its description before the commodity goes live, and more than twenty
presses inside one second - no hand on a keyboard does that; a held Up
repeats at ten - makes it switch itself off and exit, which gives the
input back. Caps Lock is ignored on all nine keys.

---

# When something is wrong

**"No BeamBender answered on the parallel port."**
Run `BBProbe ONCE` and read the five bytes. `FF FF FF FF FF` means nothing is
driving the line: check the three jumpers first, then that the card is running
firmware new enough to have the link at all.

**"The parallel port is held by ..."**
Something else has it: a printer driver, or a program that took it and did not
give it back. The name of the holder is in the message.

**The tool works but the counters climb.**
Look at the retry and failure counts on Display Info. Retries a few times a
minute on an otherwise working link are normal. A steady stream of them is a
wiring problem: too long a jumper, a dry joint, or a serial cable holding one
of the shared lines.

**A setting is greyed and you think it should not be.**
The card decides that, not the tool. A setting that does nothing in the
current output format is greyed on the card's own menu too.

**BBLink's title says a different version from the card.**
The tool was built against different firmware. It still runs, but rebuild it
against the firmware you are actually using before trusting a setting that
moved between the two.

**Your settings came back as defaults after flashing.**
The record the card saves has a format version, and when it changes the card
refuses the old record rather than reading the fields out of the wrong bytes.
Set your positions, sampling phases and capture heights once more and press
Save Settings. It will stay after that.

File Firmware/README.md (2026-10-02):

# Loading the firmware

The files in this folder are the card's firmware, two per module, named for
the module, the firmware version and the clock variant:

```
BeamBender-BigBox_i9_<version>.bit         Colorlight i9  (LFE5U-45F)
BeamBender-BigBox_i9_<version>-si1.bit     Colorlight i9, one-clock variant
BeamBender-BigBox_i5_<version>.bit         Colorlight i5  (LFE5U-25F)
BeamBender-BigBox_i5_<version>-si1.bit     Colorlight i5, one-clock variant
```

Load the one that matches the module in your card - the programmer refuses
a file for the other module, so nothing can go wrong there - and pick the
clock variant from the board:

- **A board without the Si5351C clock generator** (a revision 0.3 board
  as built): either file. Both behave the same there: the i9 clocks the
  four VESA formats from its own PLLs, the i5 offers the CEA formats and
  1920x1200.
- **A board with the Si5351C and all four of its outputs wired** (the
  revision 0.3 rework, the next revision): the plain file gives each VESA
  format its own Si5351 output; the `-si1` file drives every VESA format
  from CLK0 alone and retunes the part at each format change. Both work;
  `-si1` is the one that has had the most hours on the bench.
- **A board with only CLK0 wired**: the `-si1` file.

Either way the card measures the clocks it has at power-up and offers
only the formats it can clock, so a wrong choice costs a format, never a
picture. What follows is everything between a fresh module and a card
that boots into the firmware on its own: unlocking the module's flash
(once), a JTAG adapter, the software, and the two commands.

---

## 1. Unlock the module's flash - once, on the Colorlight dev board

A Colorlight module straight from the seller has its SPI flash
**write-protected**: the bitstream it shipped with can run, but the flash
cannot be rewritten. Until the protection bits are cleared, every attempt
to write the firmware to flash fails, however good the adapter and the
wiring.

The easiest way to clear them is with the module seated in the **Colorlight
ext-board** (the dev board sold in a bundle with the module), which has a
JTAG programmer built in. With the module on the dev board and the board
plugged into USB, run

```
ecpdap flash scan
ecpdap flash unprotect
```

`scan` shows the protection bits (`BP0: true, BP1: true, BP2: true` on a
new module); `unprotect` clears them. **This is done once.** The flash
stays unprotected from then on, through every later programming, so the
dev board is not needed again after this step. Tom Verbeure's write-up of
the i5 as a development board is where this comes from and has the detail:
<https://tomverbeure.github.io/2021/01/22/The-Colorlight-i5-as-FPGA-development-board.html>

`ecpdap` is part of the oss-cad-suite package described in section 3, so
install that first. (openFPGALoader from the same package can do the same
with `openFPGALoader -b colorlight-i5 --unprotect-flash`.)

If you skipped the dev board, the same commands work through the card's
JTAG header with your own adapter, once section 2 is done.

## 2. The JTAG adapter

The card programs the module in place, through a **1x6 JTAG header** on
the card, and the module's own JTAG pins reach it through spring-loaded
pogo pins under the SO-DIMM socket. Any JTAG adapter that openFPGALoader
supports will do; the ones that work well and cost little are the
**FTDI MPSSE** adapters:

- **FT232H** - single channel, the cheapest, and all that is needed:
  [Amazon](https://www.amazon.com/dp/B0H8CCVWT8) or
  [AliExpress](https://www.aliexpress.com/item/3256811623126850.html)
- **FT2232HL** (CJMCU-2232HL and similar) - two channels, equally good

Do **not** buy an FT232**R**L board: that chip has no MPSSE engine and
bit-bangs JTAG, which is slow enough that a bitstream takes minutes rather
than seconds.

### Wiring to the card

The header on the card (J2), pin 1 at the square pad - the signal names are also on the silkscreen next to it:

| card pin | signal | FT232H board | FT2232HL board (channel A) |
|---|---|---|---|
| 1 | TMS | D3 | AD3 |
| 2 | TDI | D1 | AD1 |
| 3 | TDO | D2 | AD2 |
| 4 | TCK | D0 | AD0 |
| 5 | GND | GND | GND |
| 6 | 3V3 | **leave unconnected** | **leave unconnected** |

Five wires: the four JTAG signals and ground. **Do not connect the
adapter's VCC / VTGT / 3V3 pin to the card.** The card is powered by the
Amiga it is plugged into, and that is how it should be powered while it is
programmed: the Amiga on, the card in its slot, the adapter supplying only
signals. A 3.3 V from the adapter would back-feed the card's rail.

On an FT232H board with an "I2C mode" switch, set it to **off** for JTAG.
Keep the wires short - a hand's length is fine - and if programming fails
at 10 MHz, drop the clock (section 4).

## 3. The software

Everything needed is in **oss-cad-suite**, a ready-built bundle of the
open-source FPGA tools for Windows, Linux and macOS - openFPGALoader,
ecpdap, and the rest. Download the build for your machine from

<https://github.com/YosysHQ/oss-cad-suite-build/releases>

unpack it anywhere, and run the tools from its `bin` folder (or add that
folder to your PATH). There is nothing to build.

**Windows 11** needs one more thing: the FTDI adapter has to be bound to
the **WinUSB** driver so openFPGALoader can talk to it directly, and the
standard FTDI driver that Windows installs on its own gets in the way.
Run [Zadig](https://zadig.akeo.ie) as administrator, tick *Options > List
All Devices*, pick the adapter (for an FT2232HL pick **Interface 0**, the
channel the JTAG is wired to), choose **WinUSB** and *Replace Driver*.
After that the adapter appears under *Universal Serial Bus devices* in
Device Manager and stays bound. The step-by-step version of this, with
the pitfalls, is at
<https://github.com/kavanoz64/JTAG-Programming-on-Windows-11>.

Check that the adapter sees the module:

```
openFPGALoader -c ft232 --detect
```

(`-c ft2232` for an FT2232HL board.) It should report a Lattice ECP5 -
`LFE5U-45F` on an i9, `LFE5U-25F` on an i5.

## 4. Loading the firmware

Two commands, one difference between them. **Into the FPGA's memory**, to
try it - it runs immediately and is gone at the next power cycle:

```
openFPGALoader -c ft232 --freq 10000000 -m BeamBender-BigBox_i9_2026-09-30.07.bit
```

**Into the module's flash**, to keep it - the card boots into it from then
on:

```
openFPGALoader -c ft232 --freq 10000000 -f BeamBender-BigBox_i9_2026-09-30.07.bit
```

That is `-m` for memory and `-f` for flash; everything else is the same.
`--freq 10000000` runs the JTAG clock at 10 MHz, which an FT232H does
comfortably over short wires and loads a bitstream in a few seconds.
Use `-c ft2232` for an FT2232HL board, and the i5 file for an i5 module.

If the flash write fails and the memory load works, the flash is still
protected: section 1.

A settings record the card has saved in its flash lives in a corner the
firmware does not touch, so your positions and sampling phases survive a
firmware update. A newer firmware reads a record written by an older one
(the current record format is version 12, and the firmware still loads
version 11 and fills in what was not there); when a change does break the
format the card says so and starts from defaults. Back your settings up
first with the BBLink tool (see the `BBLink` folder) and restore them
afterwards - the backup is a readable text file, and BBLink 1.23 or later
writes the half-step scales into it correctly.

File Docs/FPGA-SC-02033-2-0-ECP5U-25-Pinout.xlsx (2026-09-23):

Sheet: SO-DIMM-i5
Function | Top-Pin | Bank | CLK | CLK | Bank | Bot-Pin | Function |  | Clocks
GND | 1 |  | 0 | 0 |  | 2 | 5V | 0 | H4
GND | 3 |  | 0 | 0 |  | 4 | 5V | 0 | H5
GND | 5 |  | 0 | 0 |  | 6 | 5V | 0 | G3
GND | 7 |  | 0 | 0 |  | 8 | 5V | 0 | F2
GND | 9 |  | 0 | 0 |  | 10 | 5V | 0 | F3
GND | 11 |  | 0 | 0 |  | 12 | 5V | 0 | E2
NC | 13 |  | 0 | 0 |  | 14 | NC | 0 | F1
ETH1_1P | 15 |  | 0 | 0 |  | 16 | ETH2_1P | 0 | J4
ETH1_1N | 17 |  | 0 | 0 |  | 18 | ETH2_1N | 0 | L18
NC | 19 |  | 0 | 0 |  | 20 | NC | 0 | L20
ETH1_2N | 21 |  | 0 | 0 |  | 22 | ETH2_2N | 0 | K20
ETH1_2P | 23 |  | 0 | 0 |  | 24 | ETH2_2P | 0 | K19
NC | 25 |  | 0 | 0 |  | 26 | NC | 0 | J20
ETH1_3P | 27 |  | 0 | 0 |  | 28 | ETH2_3P | 0 | J19
ETH1_3N | 29 |  | 0 | 0 |  | 30 | ETH2_3N | 0 | J18
NC | 31 |  | 0 | 0 |  | 32 | NC | 0 | G19
ETH1_4N | 33 |  | 0 | 0 |  | 34 | ETH2_4N | 0
ETH1_4P | 35 |  | 0 | 0 |  | 36 | ETH2_4P | 0
NC | 37 |  | 0 | 0 |  | 38 | NC | 0
GND | 39 |  | 0 | 0 |  | 40 | GND | 0
 |  |  |  |  |  |  |  | 0
 |  |  |  |  |  |  |  | 0
U16 | 41 | 3 | 0 | 0 | 8 | 42 | R1 | 0
NC | 43 |  | 0 | 0 | 8 | 44 | T1 | 0
NC | 45 |  | 0 | 0 | 8 | 46 | U1 | 0
NC | 47 |  | 0 | 0 | 8 | 48 | Y2 | 0
K18 | 49 | 2 | 0 | 0 | 8 | 50 | W1 | 0
C18 | 51 | 2 | 0 | 0 | 8 | 52 | V1 | 0
NC | 53 |  | 0 | 0 | 6 | 54 | M1 | 0
GND | 55 |  | 0 | 0 |  | 56 | GND | 0
T18 | 57 | 3 | 0 | 0 | 6 | 58 | N2 | 0
R18 | 59 | 3 | 0 | 0 | 6 | 60 | N3 | 0
R17 | 61 | 3 | 0 | 0 | 8 | 62 | T2 | 0
P17 | 63 | 3 | 0 | 0 | 6 | 64 | M3 | 0
M17 | 65 | 3 | 0 | 0 | 8 | 66 | T3 | 0
T17 | 67 | 3 | 0 | 0 | 8 | 68 | R3 | 0
U18 | 69 | 3 | 0 | 0 | 6 | 70 | N4 | 0
U17 | 71 | 3 | 0 | 0 | 6 | 72 | M4 | 0
P18 | 73 | 3 | 0 | 0 | 6 | 74 | L4 | 0
N17 | 75 | 3 | 0 | 0 | 6 | 76 | L5 | 0
N18 | 77 | 3 | 0 | 0 | 3 | 78 | P16 | 0
M18 | 79 | 3 | 0 | 0 | 2 | 80 | J16 | 0
L20 | 81 | 3 | 1 | 1 | 2 | 82 | J18 | 2
L18 | 83 | 3 | 1 | 0 | 2 | 84 | J17 | 1
K20 | 85 | 2 | 1 | 0 | 2 | 86 | H18 | 1
K19 | 87 | 2 | 1 | 0 | 2 | 88 | H17 | 1
J20 | 89 | 2 | 1 | 0 | 2 | 90 | G18 | 1
J19 | 91 | 2 | 1 | 0 | 2 | 92 | H16 | 1
H20 | 93 | 2 | 0 | 0 | 2 | 94 | F18 | 0
G20 | 95 | 2 | 0 | 0 | 2 | 96 | G16 | 0
G19 | 97 | 2 | 1 | 0 | 2 | 98 | E18 | 1
F20 | 99 | 2 | 0 | 0 | 2 | 100 | F17 | 0
F19 | 101 | 2 | 0 | 0 | 2 | 102 | F16 | 0
E20 | 103 | 2 | 0 | 0 | 2 | 104 | E16 | 0
GND | 105 |  | 0 | 0 |  | 106 | GND | 0
GND | 107 |  | 0 | 0 |  | 108 | GND | 0
E19 | 109 | 2 | 0 | 0 | 2 | 110 | E17 | 0
D20 | 111 | 2 | 0 | 0 | 2 | 112 | D18 | 0
D19 | 113 | 2 | 0 | 0 | 2 | 114 | D17 | 0
C20 | 115 | 2 | 0 | 0 | 7 | 116 | G5 | 0
B20 | 117 | 1 | 0 | 0 | 1 | 118 | D16 | 0
B19 | 119 | 1 | 0 | 0 | 7 | 120 | F5 | 0
B18 | 121 | 1 | 0 | 0 | 0 | 122 | E6 | 0
A19 | 123 | 1 | 0 | 0 | 7 | 124 | E5 | 0
C17 | 125 | 1 | 0 | 0 | 7 | 126 | F4 | 0
A18 | 127 | 1 | 0 | 0 | 7 | 128 | E4 | 0
D3 | 129 | 7 | 0 | 1 | 6 | 130 | F1 | 1
C4 | 131 | 7 | 0 | 1 | 7 | 132 | F3 | 1
B4 | 133 | 7 | 0 | 1 | 7 | 134 | G3 | 1
C3 | 135 | 7 | 0 | 0 | 7 | 136 | H3 | 0
E3 | 137 | 7 | 0 | 1 | 7 | 138 | H4 | 1
A3 | 139 | 7 | 0 | 1 | 7 | 140 | H5 | 1
C2 | 141 | 7 | 0 | 1 | 6 | 142 | J4 | 1
B1 | 143 | 7 | 0 | 0 | 6 | 144 | J5 | 0
C1 | 145 | 7 | 0 | 0 | 6 | 146 | K3 | 0
D2 | 147 | 7 | 0 | 0 | 6 | 148 | K4 | 0
D1 | 149 | 7 | 0 | 0 | 6 | 150 | K5 | 0
E2 | 151 | 7 | 1 | 0 | 7 | 152 | B3 | 1
E1 | 153 | 7 | 0 | 0 | 7 | 154 | A2 | 0
F2 | 155 | 7 | 1 | 0 | 7 | 156 | B2 | 1
GND | 157 |  | 0 | 0 |  | 158 | GND | 0
NC | 159 |  | 0 | 0 |  | 160 | NC | 0
NC | 161 |  | 0 | 0 |  | 162 | NC | 0
NC | 163 |  | 0 | 0 |  | 164 | NC | 0
NC | 165 |  | 0 | 0 |  | 166 | NC | 0
NC | 167 |  | 0 | 0 |  | 168 | NC | 0
NC | 169 |  | 0 | 0 |  | 170 | NC | 0
NC | 171 |  | 0 | 0 |  | 172 | NC | 0
NC | 173 |  | 0 | 0 |  | 174 | NC | 0
NC | 175 |  | 0 | 0 |  | 176 | NC | 0
NC | 177 |  | 0 | 0 |  | 178 | NC | 0
NC | 179 |  | 0 | 0 |  | 180 | NC | 0
NC | 181 |  | 0 | 0 |  | 182 | NC | 0
NC | 183 |  | 0 | 0 |  | 184 | NC | 0
NC | 185 |  | 0 | 0 |  | 186 | NC | 0
NC | 187 |  | 0 | 0 |  | 188 | NC | 0
NC | 189 |  | 0 | 0 |  | 190 | NC | 0
NC | 191 |  | 0 | 0 |  | 192 | NC | 0
NC | 193 |  | 0 | 0 |  | 194 | NC | 0
NC | 195 |  | 0 | 0 |  | 196 | NC | 0
NC | 197 |  | 0 | 0 |  | 198 | NC | 0
GND | 199 |  | 0 | 0 |  | 200 | GND | 0

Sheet: FPGA-SC-02033-2-0-ECP5U-25-Pino
PAD | Pin/Ball Function | Bank | Dual Function | Differential | High Speed | DQS | CABGA381 | SO-DIMM Pin
1 | PL2A | 7 | - | True_OF_PL2B | TRUE | LDQ8 | A4
2 | PL2B | 7 | - | Comp_OF_PL2A | TRUE | LDQ8 | A5
3 | VSSIO7 | - | - | - | - | - | -
4 | PL2C | 7 | - | True_OF_PL2D | - | LDQ8 | B5
5 | VCCIO7 | - | - | - | - | - | -
6 | PL2D | 7 | - | Comp_OF_PL2C | - | LDQ8 | C5
7 | PL5A | 7 | - | True_OF_PL5B | TRUE | LDQ8 | C4 | 131
8 | VCCAUX | - | - | - | - | - | -
9 | PL5C | 7 | - | True_OF_PL5D | - | LDQ8 | A3 | 139
10 | PL5B | 7 | - | Comp_OF_PL5A | TRUE | LDQ8 | B4 | 133
11 | VSS | - | - | - | - | - | -
12 | PL5D | 7 | - | Comp_OF_PL5C | - | LDQ8 | B3 | 152
13 | PL8A | 7 | - | True_OF_PL8B | TRUE | LDQS8 | E4 | 128
14 | VCC | - | - | - | - | - | -
15 | PL8C | 7 | - | True_OF_PL8D | - | LDQ8 | C3 | 135
16 | PL8B | 7 | - | Comp_OF_PL8A | TRUE | LDQSN8 | D5
17 | VSS | - | - | - | - | - | -
18 | PL8D | 7 | - | Comp_OF_PL8C | - | LDQ8 | D3 | 129
19 | PL11A | 7 | - | True_OF_PL11B | TRUE | LDQ8 | F4 | 126
20 | VSSIO7 | - | - | - | - | - | -
21 | PL11C | 7 | - | True_OF_PL11D | - | LDQ8 | E5 | 124
22 | PL11B | 7 | - | Comp_OF_PL11A | TRUE | LDQ8 | E3 | 137
23 | VCCIO7 | - | - | - | - | - | -
24 | PL11D | 7 | - | Comp_OF_PL11C | - | LDQ8 | F5 | 120
25 | PL14A | 7 | - | True_OF_PL14B | TRUE | LDQ20 | A2 | 154
26 | VSSIO7 | - | - | - | - | - | -
27 | PL14C | 7 | VREF1_7 | True_OF_PL14D | - | LDQ20 | B2 | 156
28 | PL14B | 7 | - | Comp_OF_PL14A | TRUE | LDQ20 | B1 | 143
29 | VCCIO7 | - | - | - | - | - | -
30 | PL14D | 7 | - | Comp_OF_PL14C | - | LDQ20 | C2 | 141
31 | PL17A | 7 | - | True_OF_PL17B | TRUE | LDQ20 | C1 | 145
32 | VCCAUX | - | - | - | - | - | -
33 | PL17C | 7 | - | True_OF_PL17D | - | LDQ20 | D2 | 147
34 | PL17B | 7 | - | Comp_OF_PL17A | TRUE | LDQ20 | D1 | 149
35 | VSS | - | - | - | - | - | -
36 | PL17D | 7 | - | Comp_OF_PL17C | - | LDQ20 | E1 | 153
37 | PL20A | 7 | GR_PCLK7_1 | True_OF_PL20B | TRUE | LDQS20 | H4 | 138 |  | 138
38 | VCC | - | - | - | - | - | -
39 | PL20C | 7 | GR_PCLK7_0 | True_OF_PL20D | - | LDQ20 | H5 | 140 |  | 140
40 | PL20B | 7 | - | Comp_OF_PL20A | TRUE | LDQSN20 | G5 | 116
41 | VSS | - | - | - | - | - | -
42 | PL20D | 7 | - | Comp_OF_PL20C | - | LDQ20 | H3 | 136
43 | PL23A | 7 | PCLKT7_1 | True_OF_PL23B | TRUE | LDQ20 | G3 | 134 |  | 134
44 | VSSIO7 | - | - | - | - | - | -
45 | PL23C | 7 | PCLKT7_0 | True_OF_PL23D | - | LDQ20 | F2 | 155 | 155
46 | PL23B | 7 | PCLKC7_1 | Comp_OF_PL23A | TRUE | LDQ20 | F3 | 132
47 | VCCIO7 | - | - | - | - | - | -
48 | PL23D | 7 | PCLKC7_0 | Comp_OF_PL23C | - | LDQ20 | E2 | 151
49 | PL26A | 6 | PCLKT6_1 | True_OF_PL26B | TRUE | LDQ32 | G2
50 | VSSIO6 | - | - | - | - | - | -
51 | PL26C | 6 | PCLKT6_0 | True_OF_PL26D | - | LDQ32 | H2
52 | PL26B | 6 | PCLKC6_1 | Comp_OF_PL26A | TRUE | LDQ32 | F1 | 130
53 | VCCIO6 | - | - | - | - | - | -
54 | PL26D | 6 | PCLKC6_0 | Comp_OF_PL26C | - | LDQ32 | G1
55 | PL29A | 6 | GR_PCLK6_0 | True_OF_PL29B | TRUE | LDQ32 | J4 | 142 |  | 142
56 | VCCAUX | - | - | - | - | - | -
57 | PL29C | 6 | GR_PCLK6_1 | True_OF_PL29D | - | LDQ32 | J3
58 | PL29B | 6 | - | Comp_OF_PL29A | TRUE | LDQ32 | J5 | 144
59 | VSS | - | - | - | - | - | -
60 | PL29D | 6 | - | Comp_OF_PL29C | - | LDQ32 | K3 | 146
61 | PL32A | 6 | - | True_OF_PL32B | TRUE | LDQS32 | K2
62 | VCC | - | - | - | - | - | -
63 | PL32C | 6 | - | True_OF_PL32D | - | LDQ32 | H1
64 | PL32B | 6 | - | Comp_OF_PL32A | TRUE | LDQSN32 | J1
65 | VSS | - | - | - | - | - | -
66 | PL32D | 6 | - | Comp_OF_PL32C | - | LDQ32 | K1
67 | PL35A | 6 | - | True_OF_PL35B | TRUE | LDQ32 | K4 | 148
68 | VSSIO6 | - | - | - | - | - | -
69 | PL35C | 6 | - | True_OF_PL35D | - | LDQ32 | L4 | 74
70 | PL35B | 6 | VREF1_6 | Comp_OF_PL35A | TRUE | LDQ32 | K5 | 150
71 | VCCIO6 | - | - | - | - | - | -
72 | PL35D | 6 | - | Comp_OF_PL35C | - | LDQ32 | L5 | 76
73 | PL38A | 6 | - | True_OF_PL38B | TRUE | LDQ44 | M4 | 72
74 | VSSIO6 | - | - | - | - | - | -
75 | PL38C | 6 | - | True_OF_PL38D | - | LDQ44 | N4 | 70
76 | PL38B | 6 | - | Comp_OF_PL38A | TRUE | LDQ44 | N5
77 | VCCIO6 | - | - | - | - | - | -
78 | PL38D | 6 | - | Comp_OF_PL38C | - | LDQ44 | P5
79 | PL41A | 6 | - | True_OF_PL41B | TRUE | LDQ44 | N3 | 60
80 | VCCAUX | - | - | - | - | - | -
81 | PL41C | 6 | - | True_OF_PL41D | - | LDQ44 | L3
82 | PL41B | 6 | - | Comp_OF_PL41A | TRUE | LDQ44 | M3 | 64
83 | VSS | - | - | - | - | - | -
84 | PL41D | 6 | - | Comp_OF_PL41C | - | LDQ44 | L2
85 | PL44A | 6 | - | True_OF_PL44B | TRUE | LDQS44 | N2 | 58
86 | VCC | - | - | - | - | - | -
87 | PL44C | 6 | - | True_OF_PL44D | - | LDQ44 | L1
88 | PL44B | 6 | - | Comp_OF_PL44A | TRUE | LDQSN44 | M1 | 54
89 | VSS | - | - | - | - | - | -
90 | PL44D | 6 | - | Comp_OF_PL44C | - | LDQ44 | N1
91 | PL47A | 6 | - | True_OF_PL47B | TRUE | LDQ44 | P1
92 | VSSIO6 | - | - | - | - | - | -
93 | PL47B | 6 | - | Comp_OF_PL47A | TRUE | LDQ44 | P2
94 | VCCIO6 | - | - | - | - | - | -
95 | PL47C | 6 | LLC_GPLL0T_IN | True_OF_PL47D | - | LDQ44 | P3
96 | PL47D | 6 | LLC_GPLL0C_IN | Comp_OF_PL47C | - | LDQ44 | P4
97 | NC | - | - | - | - | - | -
98 | NC | - | - | - | - | - | -
99 | GND | - | - | - | - | - | -
100 | VCC | - | - | - | - | - | -
101 | VCC | - | - | - | - | - | -
102 | VSS | - | - | - | - | - | -
103 | PB4A | 8 | D7/IO7 | True_OF_PB4B | - | - | R1 | 42
104 | PB6A | 8 | D5/MISO2/IO5 | True_OF_PB6B | - | - | U1 | 46
105 | VCC | - | - | - | - | - | -
106 | PB4B | 8 | D6/IO6 | Comp_OF_PB4A | - | - | T1 | 44
107 | PB6B | 8 | D4/MOSI2/IO4 | Comp_OF_PB6A | - | - | V1 | 52
108 | VSS | - | - | - | - | - | -
109 | PB9A | 8 | D3/IO3 | True_OF_PB9B | - | - | W1 | 50
110 | PB11A | 8 | D1/MISO/IO1 | True_OF_PB11B | - | - | V2
111 | VSSIO8 | - | - | - | - | - | -
112 | PB9B | 8 | D2/IO2 | Comp_OF_PB9A | - | - | Y2 | 48
113 | PB11B | 8 | D0/MOSI/IO0 | Comp_OF_PB11A | - | - | W2
114 | VCCIO8 | - | - | - | - | - | -
115 | PB13A | 8 | SN/CSN | True_OF_PB13B | - | - | T2 | 62
116 | PB15A | 8 | HOLDN/DI/BUSY/CSSPIN/CEN | True_OF_PB15B | - | - | R2
117 | VSSIO8 | - | - | - | - | - | -
118 | PB13B | 8 | CS1N | Comp_OF_PB13A | - | - | U2
119 | PB15B | 8 | DOUT/CSON | Comp_OF_PB15A | - | - | R3 | 68
120 | VCCIO8 | - | - | - | - | - | -
121 | PB18A | 8 | WRITEN | - | - | - | T3 | 66
122 | INITN | 8 | - | - | - | - | V3
123 | VCCAUX | - | - | - | - | - | -
124 | CCLK | 8 | MCLK/SCK | - | - | - | U3
125 | PROGRAMN | 8 | - | - | - | - | W3
126 | VSS | - | - | - | - | - | -
127 | DONE | 8 | - | - | - | - | Y3
128 | CFG_1 | 8 | - | - | - | - | T4
129 | VCC | - | - | - | - | - | -
130 | CFG_2 | 8 | - | - | - | - | R4
131 | CFG_0 | 8 | - | - | - | - | U4
132 | VSS | - | - | - | - | - | -
133 | TDO | 40 | - | - | - | - | V4
134 | TCK | 40 | - | - | - | - | T5
135 | VSSIO8 | - | - | - | - | - | -
136 | TDI | 40 | - | - | - | - | R5
137 | TMS | 40 | - | - | - | - | U5
138 | VCCIO8 | - | - | - | - | - | -
139 | VCC | - | - | - | - | - | -
140 | VCC | - | - | - | - | - | -
141 | VSS | - | - | - | - | - | -
142 | VSS | - | - | - | - | - | -
143 | VCC | - | - | - | - | - | -
144 | VCC | - | - | - | - | - | -
145 | GND | - | - | - | - | - | -
146 | GND | - | - | - | - | - | -
147 | RESERVED | - | - | - | - | - | W4
148 | GND | - | - | - | - | - | T7
149 | RESERVED | - | - | - | - | - | W5
150 | GND | - | - | - | - | - | -
151 | GND | - | - | - | - | - | -
152 | GND | - | - | - | - | - | Y5
153 | GND | - | - | - | - | - | -
154 | GND | - | - | - | - | - | T8
155 | GND | - | - | - | - | - | Y6
156 | GND | - | - | - | - | - | -
157 | GND | - | - | - | - | - | -
158 | GND | - | - | - | - | - | Y7
159 | GND | - | - | - | - | - | -
160 | GND | - | - | - | - | - | T9
161 | GND | - | - | - | - | - | Y8
162 | GND | - | - | - | - | - | -
163 | GND | - | - | - | - | - | -
164 | RESERVED | - | - | - | - | - | W8
165 | GND | - | - | - | - | - | T10
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

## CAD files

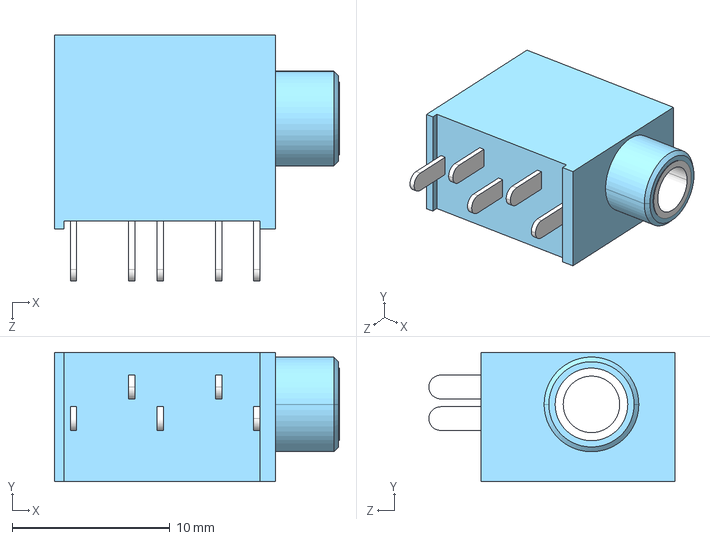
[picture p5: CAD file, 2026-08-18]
3Dmodels/SJ1-3535NG.stp
18.1 x 8.20 x 15.6 mm

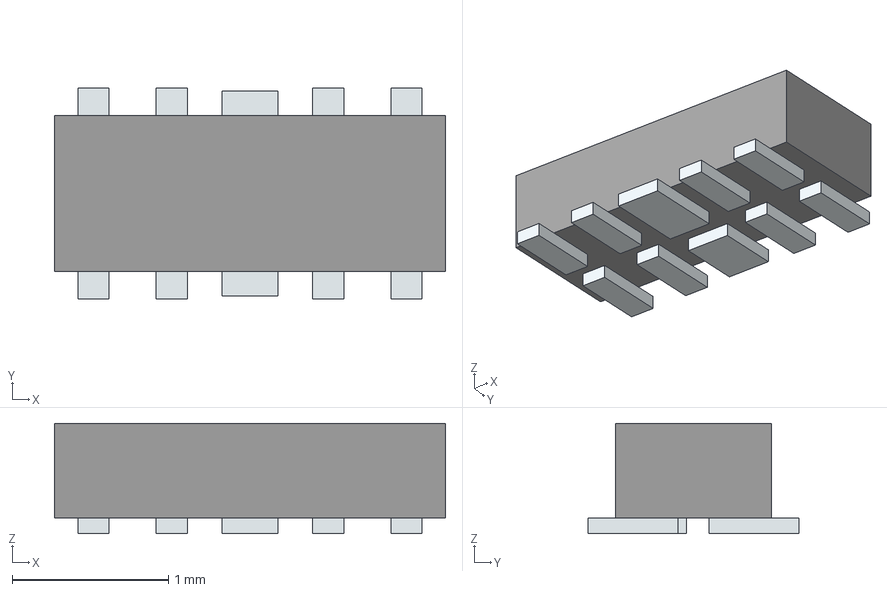
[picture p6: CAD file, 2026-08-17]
3Dmodels/D5V0F4U10LP-7.stp
2.50 x 1.35 x 0.705 mm
Pins

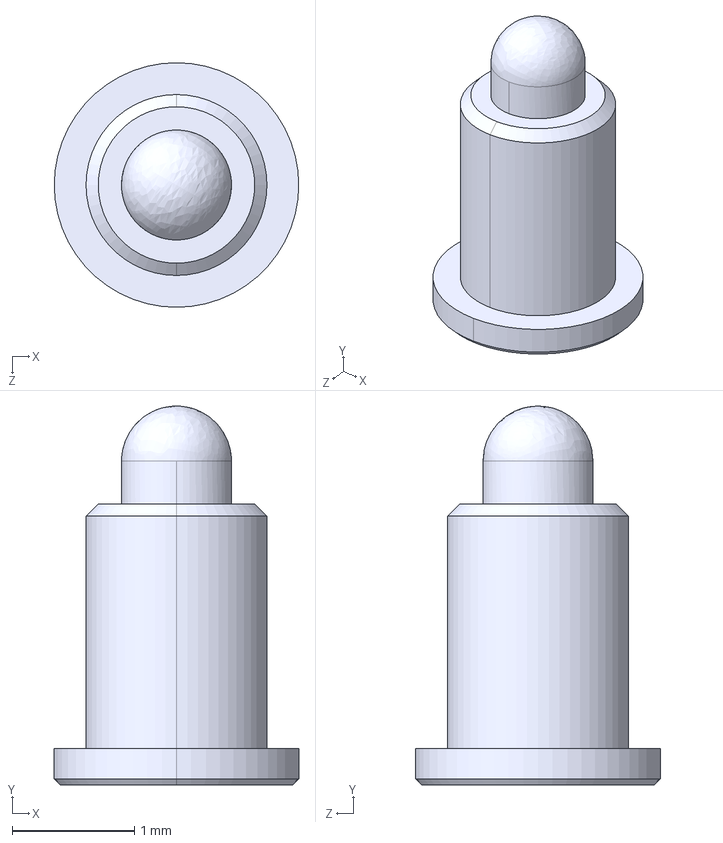
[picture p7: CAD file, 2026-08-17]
3Dmodels/PogoPin.stp
2.00 x 3.10 x 2.00 mm

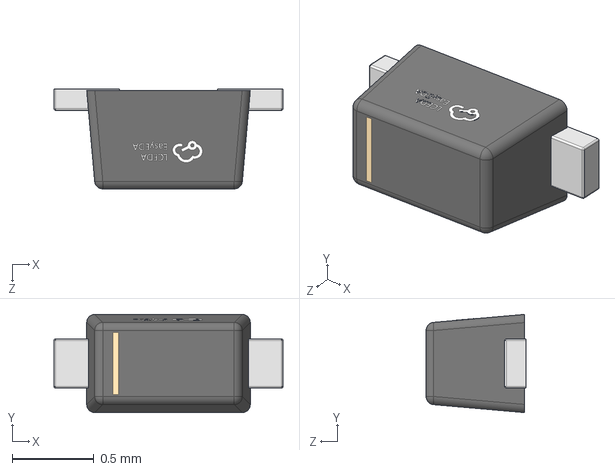
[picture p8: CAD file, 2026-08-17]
3Dmodels/SOD-723_L1.0-W0.6-H0.6-LS1.4-RD.stp
1.40 x 0.6 x 0.61 mm

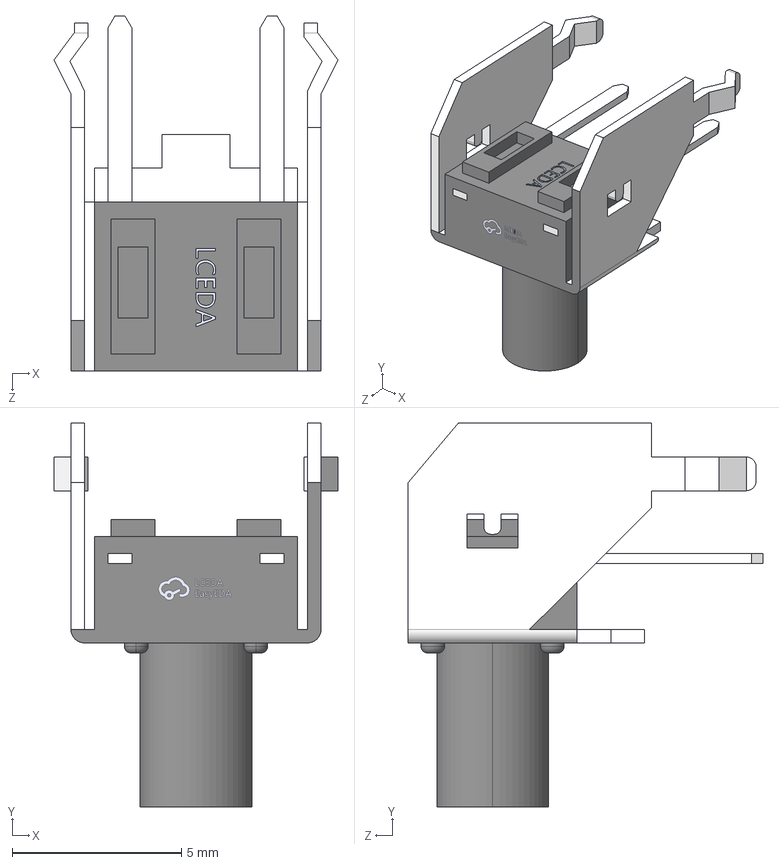
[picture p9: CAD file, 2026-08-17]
3Dmodels/KEY-TH_TS-1038-A10B3-D2.stp
8.40 x 11.3 x 10.5 mm

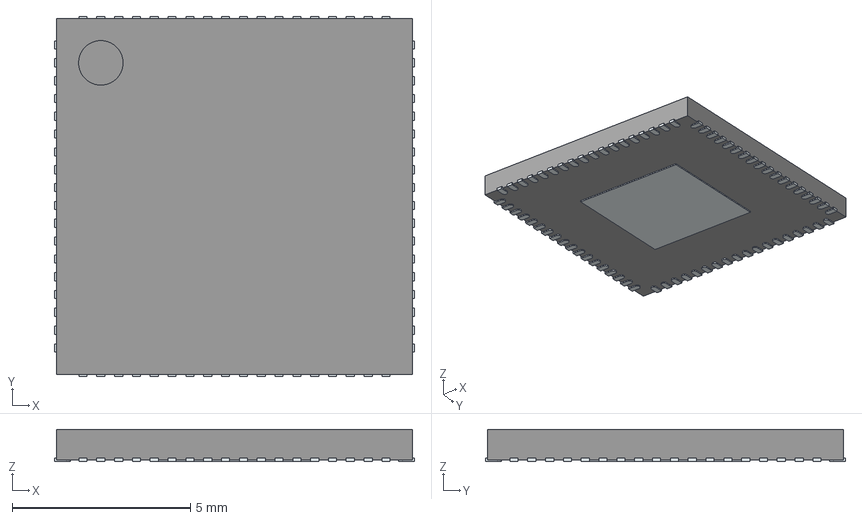
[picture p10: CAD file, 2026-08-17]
3Dmodels/SII9022ACNU.stp
10.1 x 10.1 x 0.9 mm
ThermalPin
PinsArrayLR
PinsArrayTB

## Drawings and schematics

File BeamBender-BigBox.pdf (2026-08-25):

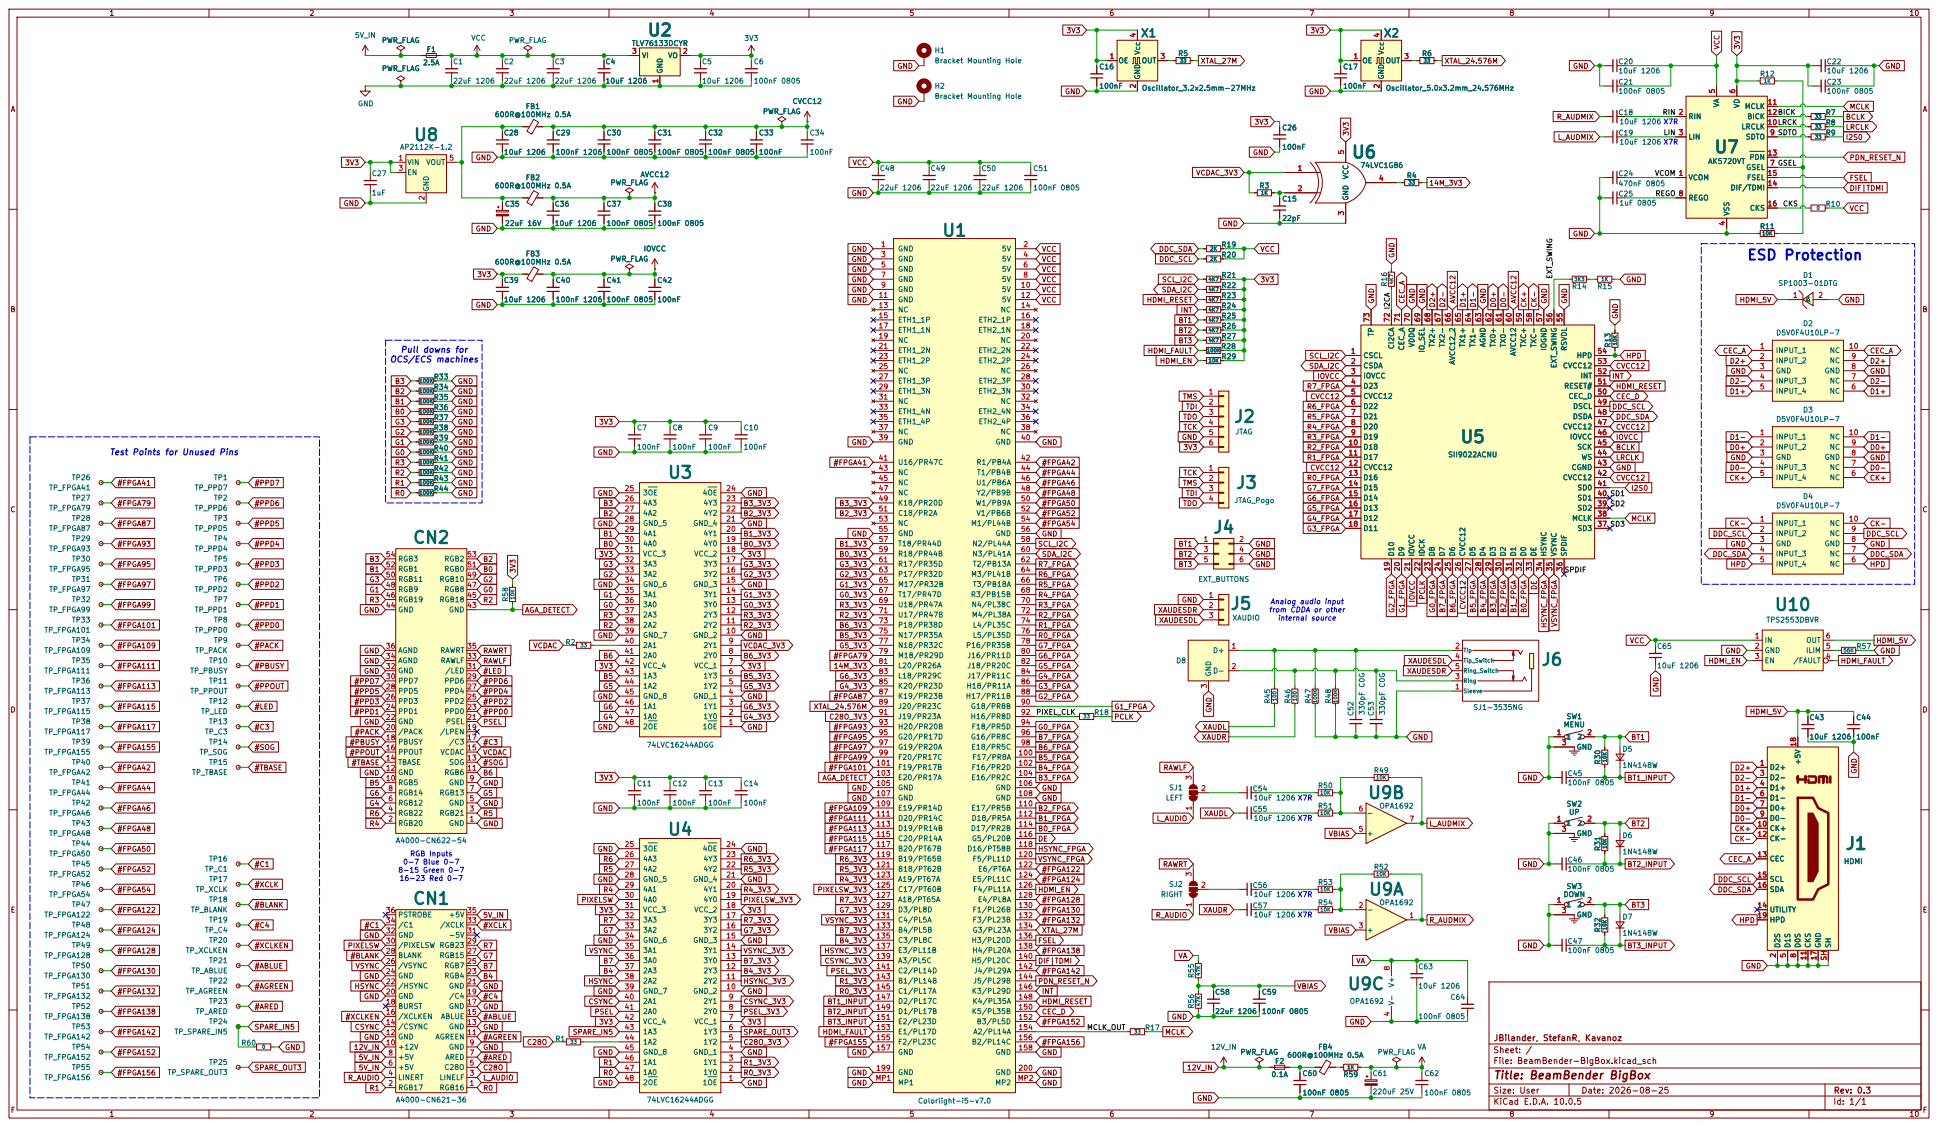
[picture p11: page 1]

54 RSVDL 55 EXT_SWING 56 IOGND 57 TXC- 58 TXC+ 59 AVCC12 60 TX0- 61 TX0+ 62 AGND 63 TX1- 64 TX1+ 65 AVCC12_2 66 TX2- 67 TX2+ 68 IO_SEL 69 VDDQ 70 CEC_A 71 CI2CA 72 TP 73

Test Points for Unused Pins

Analog audio input
from CDDA or other

Size: User | Rev: 0.3 | F Date: 2026-08-25
KiCad E.D.A. 10.0.5 | Id: 1/1

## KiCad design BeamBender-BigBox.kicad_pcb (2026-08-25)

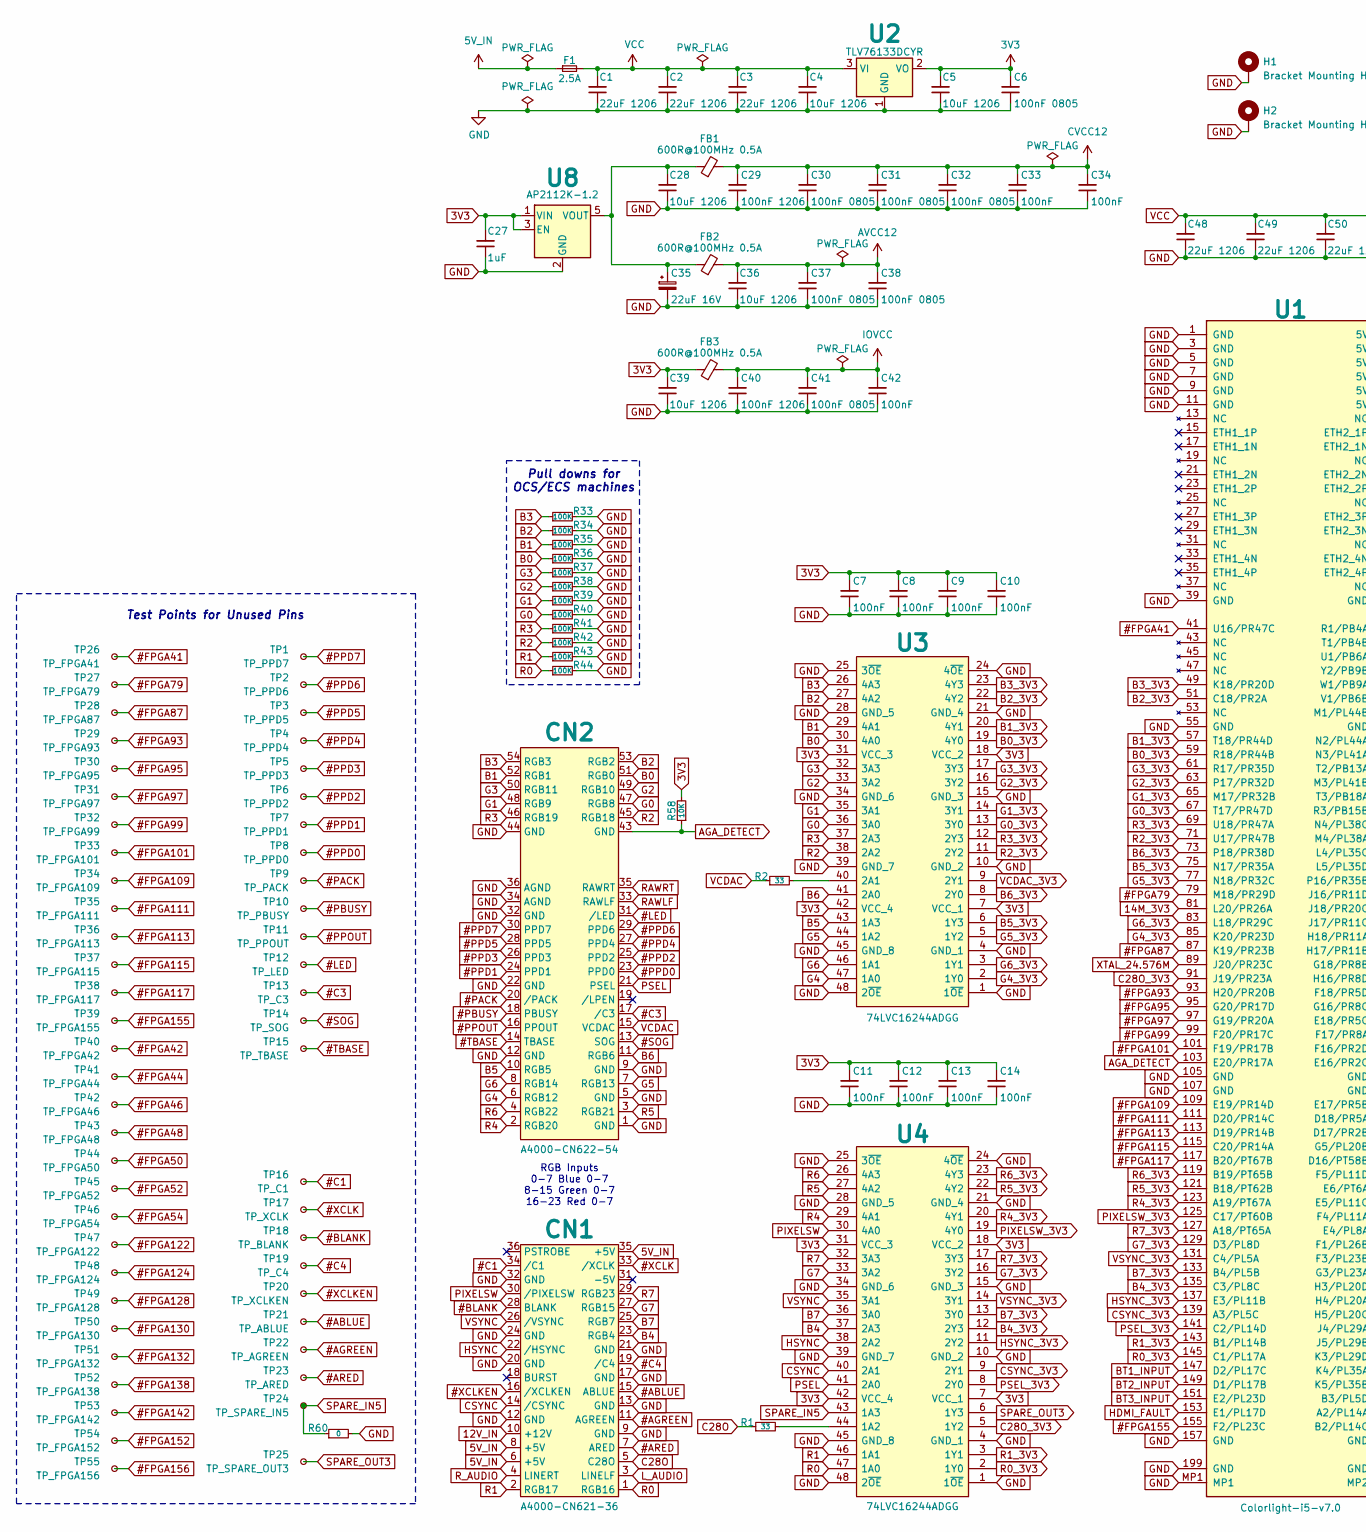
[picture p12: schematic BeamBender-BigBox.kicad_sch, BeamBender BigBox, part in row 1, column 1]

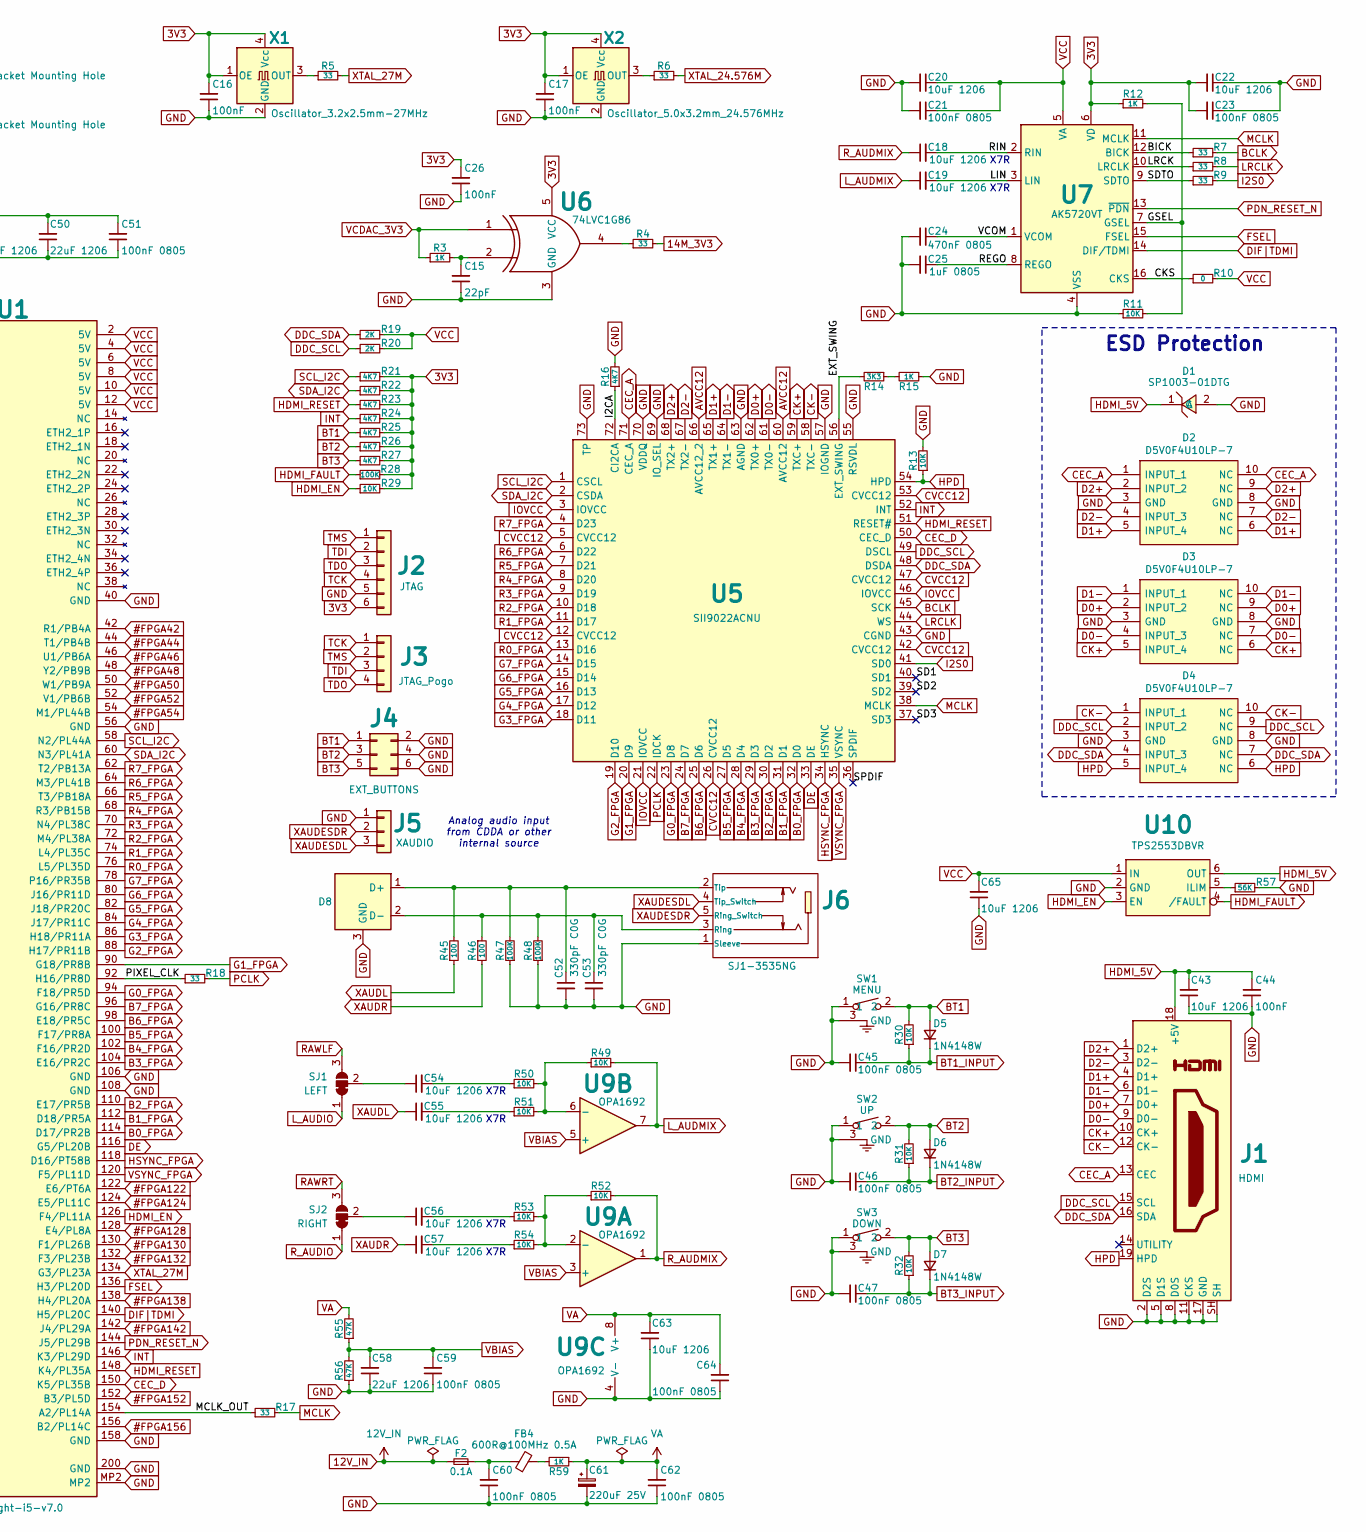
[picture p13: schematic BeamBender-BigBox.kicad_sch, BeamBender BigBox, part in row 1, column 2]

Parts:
C1, C2, C3, C48, C49, C50, C58: 22uF 1206; C_1206_3216Metric; MPN CL31A226KOHNNNE; LCSC C90146
C4, C5, C18, C19, C20, C22, C28, C36, C39, C43, C54, C55, C56, C57, C63, C65: 10uF 1206; C_1206_3216Metric; MPN CL31B106KPHNNNE; LCSC C96449
C6, C21, C23, C30, C31, C32, C37, C38, C41, C45, C46, C47, C51, C59, C60, C62, C64: 100nF 0805; C_0805_2012Metric; MPN CL21B104KCFNNNE; LCSC C28233
C7, C8, C9, C10, C11, C12, C13, C14, C16, C17, C26, C33, C34, C42, C44: 100nF; C_0603_1608Metric; MPN CC0603KRX7R9BB104; LCSC C14663
C15: 22pF; C_0603_1608Metric; MPN CL10C220JB8NNNC; LCSC C1653
C24: 470nF 0805; C_0805_2012Metric; MPN CL21B474KBFNNNE; LCSC C13967
C25: 1uF 0805; C_0805_2012Metric; MPN CL21B105KBFNNNE; LCSC C28323
C27: 1uF; C_0603_1608Metric; MPN CL10A105KB8NNNC; LCSC C15849
C29, C40: 100nF 1206; C_1206_3216Metric; MPN CL31B104KBCNNNC; LCSC C24497
C35: 22uF 16V; CP_Elec_5x5.8; MPN UWT1C220MCL1GB; LCSC C445073
C52, C53: 330pF C0G; C_0603_1608Metric; MPN CL10C331JB8NNNC; LCSC C1664
C61: 220uF 25V; CP_Elec_6.3x7.7; MPN EEEFTE221XAP; LCSC C190724
CN1: A4000-CN621-36
CN2: A4000-CN622-54
D1: SP1003-01DTG; SOD-723_L1.0-W0.6-LS1.4-RD; MPN SP1003-01DTG; LCSC C126834
D2, D3, D4: D5V0F4U10LP-7; Diodes_UDFN-10_1.0x2.5mm_P0.5mm_HandSolder; MPN D5V0F4U10LP-7; LCSC C460833
D5, D6, D7: 1N4148W; D_SOD-123; MPN 1N4148W; LCSC C81598
D8: TPD2E009; SOT-23; MPN TPD2E009DBZR; LCSC C2871371
F1: 2.5A; Fuse_1206_3216Metric; MPN 1206L250/16AR; LCSC C42449089
F2: 0.1A; Fuse_1206_3216Metric; MPN JK-nSMD010/60V; LCSC C2830236
FB1, FB2, FB3, FB4: 600R@100MHz 0.5A; L_0805_2012Metric; MPN GZ2012D601TF; LCSC C1017
H1, H2: Bracket Mounting Hole; MountingHole_3.2mm_M3_Pad_Via
J1: HDMI; HDMI_A_Molex_208658-1001_Horizontal; MPN HDMI-001 19PCBTP; LCSC C138388
J2: JTAG; PinHeader_1x06_P2.54mm_Vertical; MPN HB-PH3-25416PB2GOP; LCSC C6332199
J3: JTAG_Pogo; PinHeader_1x04_P2.54mm_Pogo
J4: EXT_BUTTONS; PinHeader_2x03_P2.54mm_Vertical; MPN 2541WV-2x03P; LCSC C5383104
J5: XAUDIO; PinHeader_1x03_P2.54mm_Vertical; MPN 2541WV-03P; LCSC C5383112
J6: SJ1-3535NG; AUDIO-TH_SJ1-3535NG; MPN SJ1-3535NG; LCSC C4991610
R1, R2, R4, R5, R6, R7, R8, R9, R17, R18: 33; R_0603_1608Metric; MPN 0603WAF330JT5E; LCSC C23140
R3, R12, R15, R59: 1K; R_0603_1608Metric; MPN 0603WAF1001T5E; LCSC C21190
R10, R60: 0; R_0603_1608Metric; MPN 0603WAF0000T5E; LCSC C21189
R11, R13, R29, R30, R31, R32, R49, R50, R51, R52, R53, R54, R58: 10K; R_0603_1608Metric; MPN 0603WAF1002T5E; LCSC C25804
R14: 3K3; R_0603_1608Metric; MPN 0603WAF3301T5E; LCSC C22978
R16, R21, R22, R23, R24, R25, R26, R27: 4K7; R_0603_1608Metric; MPN 0603WAF4701T5E; LCSC C23162
R19, R20: 2K; R_0603_1608Metric; MPN 0603WAF2001T5E; LCSC C22975
R28, R33, R34, R35, R36, R37, R38, R39, R40, R41, R42, R43, R44, R47, R48: 100K; R_0603_1608Metric; MPN 0603WAF1003T5E; LCSC C25803
R45, R46: 100; R_0603_1608Metric; MPN 0603WAF1000T5E; LCSC C22775
R55, R56: 47K; R_0603_1608Metric; MPN 0603WAF4702T5E; LCSC C25819
R57: 56K; R_0603_1608Metric; MPN 0603WAF5602T5E; LCSC C23206
SJ1: LEFT; SolderJumper-3_P1.3mm_Bridged12_RoundedPad1.0x1.5mm
SJ2: RIGHT; SolderJumper-3_P1.3mm_Bridged12_RoundedPad1.0x1.5mm
SW1: MENU; KEY-TH_TS-1038-A10B3-D2; MPN TS-1038-A10B3-D2; LCSC C499341
SW2: UP; KEY-TH_TS-1038-A10B3-D2; MPN TS-1038-A10B3-D2; LCSC C499341
SW3: DOWN; KEY-TH_TS-1038-A10B3-D2; MPN TS-1038-A10B3-D2; LCSC C499341
TP1: TP_PPD7; TestPoint_Pad_D1.0mm
TP2: TP_PPD6; TestPoint_Pad_D1.0mm
TP3: TP_PPD5; TestPoint_Pad_D1.0mm
TP4: TP_PPD4; TestPoint_Pad_D1.0mm
TP5: TP_PPD3; TestPoint_Pad_D1.0mm
TP6: TP_PPD2; TestPoint_Pad_D1.0mm
TP7: TP_PPD1; TestPoint_Pad_D1.0mm
TP8: TP_PPD0; TestPoint_Pad_D1.0mm
TP9: TP_PACK; TestPoint_Pad_D1.0mm
TP10: TP_PBUSY; TestPoint_Pad_D1.0mm
TP11: TP_PPOUT; TestPoint_Pad_D1.0mm
TP12: TP_LED; TestPoint_Pad_D1.0mm
TP13: TP_C3; TestPoint_Pad_D1.0mm
TP14: TP_SOG; TestPoint_Pad_D1.0mm
TP15: TP_TBASE; TestPoint_Pad_D1.0mm
TP16: TP_C1; TestPoint_Pad_D1.0mm
TP17: TP_XCLK; TestPoint_Pad_D1.0mm
TP18: TP_BLANK; TestPoint_Pad_D1.0mm
TP19: TP_C4; TestPoint_Pad_D1.0mm
TP20: TP_XCLKEN; TestPoint_Pad_D1.0mm
TP21: TP_ABLUE; TestPoint_Pad_D1.0mm
TP22: TP_AGREEN; TestPoint_Pad_D1.0mm
TP23: TP_ARED; TestPoint_Pad_D1.0mm
TP24: TP_SPARE_IN5; TestPoint_Pad_D1.0mm
TP25: TP_SPARE_OUT3; TestPoint_Pad_D1.0mm
TP26: TP_FPGA41; TestPoint_Pad_D1.0mm
TP27: TP_FPGA79; TestPoint_Pad_D1.0mm
TP28: TP_FPGA87; TestPoint_Pad_D1.0mm
TP29: TP_FPGA93; TestPoint_Pad_D1.0mm
TP30: TP_FPGA95; TestPoint_Pad_D1.0mm
TP31: TP_FPGA97; TestPoint_Pad_D1.0mm
TP32: TP_FPGA99; TestPoint_Pad_D1.0mm
TP33: TP_FPGA101; TestPoint_Pad_D1.0mm
TP34: TP_FPGA109; TestPoint_Pad_D1.0mm
TP35: TP_FPGA111; TestPoint_Pad_D1.0mm
TP36: TP_FPGA113; TestPoint_Pad_D1.0mm
TP37: TP_FPGA115; TestPoint_Pad_D1.0mm
TP38: TP_FPGA117; TestPoint_Pad_D1.0mm
TP39: TP_FPGA155; TestPoint_Pad_D1.0mm
TP40: TP_FPGA42; TestPoint_Pad_D1.0mm
TP41: TP_FPGA44; TestPoint_Pad_D1.0mm
TP42: TP_FPGA46; TestPoint_Pad_D1.0mm
TP43: TP_FPGA48; TestPoint_Pad_D1.0mm
TP44: TP_FPGA50; TestPoint_Pad_D1.0mm
TP45: TP_FPGA52; TestPoint_Pad_D1.0mm
TP46: TP_FPGA54; TestPoint_Pad_D1.0mm
TP47: TP_FPGA122; TestPoint_Pad_D1.0mm
TP48: TP_FPGA124; TestPoint_Pad_D1.0mm
TP49: TP_FPGA128; TestPoint_Pad_D1.0mm
TP50: TP_FPGA130; TestPoint_Pad_D1.0mm
TP51: TP_FPGA132; TestPoint_Pad_D1.0mm
TP52: TP_FPGA138; TestPoint_Pad_D1.0mm
TP53: TP_FPGA142; TestPoint_Pad_D1.0mm
TP54: TP_FPGA152; TestPoint_Pad_D1.0mm
TP55: TP_FPGA156; TestPoint_Pad_D1.0mm
U1: Colorlight-i5-v7.0; 1473149-4; MPN 1473149-4; LCSC C591654
U2: TLV76133DCYR; SOT-223-3_TabPin2; MPN TLV76133DCYR; LCSC C7527500
U3, U4: 74LVC16244ADGG; TSSOP-48_6.1x12.5mm_P0.5mm; MPN 74LVC16244ADGG,118; LCSC C6070
U5: SII9022ACNU; QFN-72-1EP_10x10mm_P0.5mm_EP6x6mm_ThermalVias_HandSolder; MPN SII9022ACNU; LCSC C369565
U6: 74LVC1G86; SOT-23-5; MPN SN74LVC1G86DBVR; LCSC C402161
U7: AK5720VT; TSSOP-16_4.4x5mm_P0.65mm; MPN AK5720VT; LCSC C1519002
U8: AP2112K-1.2; SOT-23-5; MPN AP2112K-1.2TRG1; LCSC C460310
U9: OPA1692; SOIC-8_3.9x4.9mm_P1.27mm; MPN OPA1692IDR; LCSC C2060550
U10: TPS2553DBVR; SOT-23-6; MPN TPS2553DBVR; LCSC C55266
X1: Oscillator_3.2x2.5mm-27MHz; Crystal_SMD_3225-4Pin_3.2x2.5mm; MPN XOS32027000LT00351005; LCSC C37635418
X2: Oscillator_5.0x3.2mm_24.576MHz; Oscillator_SMD_EuroQuartz_XO53-4Pin_5.0x3.2mm; MPN SX5M24.576M20F30TNN; LCSC C2901534

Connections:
3V3: C5.2, C6.2, C7.2, C8.2, C9.2, C10.2, C11.2, C12.2, C13.2, C14.2, C16.2, C17.2, C22.2, C23.2, C26.2, C27.2, C39.2, FB3.1, J2.6, R12.1, R21.2, R22.2, R23.2, R24.2, R25.2, R26.2, R27.2, R28.2, R29.2, R58.2, U2.2 (VO), U3.7 (VCC_1), U3.18 (VCC_2), U3.31 (VCC_3), U3.42 (VCC_4), U4.7 (VCC_1), U4.18 (VCC_2), U4.31 (VCC_3), U4.42 (VCC_4), U6.5 (VCC), U7.6 (VD), U8.1 (VIN), U8.3 (EN), X1.1 (OE), X1.4 (Vcc), X2.1 (OE), X2.4 (Vcc)
5V_IN: CN1.6 (+5V), CN1.8 (+5V), CN1.35 (+5V), F1.1
12V_IN: CN1.10 (+12V), F2.2
14M_3V3: R4.2, U1.81 (L20/PR26A)
#ABLUE: CN1.15 (ABLUE), TP21.1 (1_1)
#AGREEN: CN1.11 (AGREEN), TP22.1 (1_1)
#ARED: CN1.7 (ARED), TP23.1 (1_1)
#BLANK: CN1.28 (BLANK), TP18.1 (1_1)
#C1: CN1.34 (/C1), TP16.1 (1_1)
#C3: CN2.17 (/C3), TP13.1 (1_1)
#C4: CN1.19 (/C4), TP19.1 (1_1)
#FPGA41: TP26.1 (1_1), U1.41 (U16/PR47C)
#FPGA42: TP40.1 (1_1), U1.42 (R1/PB4A)
#FPGA44: TP41.1 (1_1), U1.44 (T1/PB4B)
#FPGA46: TP42.1 (1_1), U1.46 (U1/PB6A)
#FPGA48: TP43.1 (1_1), U1.48 (Y2/PB9B)
#FPGA50: TP44.1 (1_1), U1.50 (W1/PB9A)
#FPGA52: TP45.1 (1_1), U1.52 (V1/PB6B)
#FPGA54: TP46.1 (1_1), U1.54 (M1/PL44B)
#FPGA79: TP27.1 (1_1), U1.79 (M18/PR29D)
#FPGA87: TP28.1 (1_1), U1.87 (K19/PR23B)
#FPGA93: TP29.1 (1_1), U1.93 (H20/PR20B)
#FPGA95: TP30.1 (1_1), U1.95 (G20/PR17D)
#FPGA97: TP31.1 (1_1), U1.97 (G19/PR20A)
#FPGA99: TP32.1 (1_1), U1.99 (F20/PR17C)
#FPGA101: TP33.1 (1_1), U1.101 (F19/PR17B)
#FPGA109: TP34.1 (1_1), U1.109 (E19/PR14D)
#FPGA111: TP35.1 (1_1), U1.111 (D20/PR14C)
#FPGA113: TP36.1 (1_1), U1.113 (D19/PR14B)
#FPGA115: TP37.1 (1_1), U1.115 (C20/PR14A)
#FPGA117: TP38.1 (1_1), U1.117 (B20/PT67B)
#FPGA122: TP47.1 (1_1), U1.122 (E6/PT6A)
#FPGA124: TP48.1 (1_1), U1.124 (E5/PL11C)
#FPGA128: TP49.1 (1_1), U1.128 (E4/PL8A)
#FPGA130: TP50.1 (1_1), U1.130 (F1/PL26B)
#FPGA132: TP51.1 (1_1), U1.132 (F3/PL23B)
#FPGA138: TP52.1 (1_1), U1.138 (H4/PL20A)
#FPGA142: TP53.1 (1_1), U1.142 (J4/PL29A)
#FPGA152: TP54.1 (1_1), U1.152 (B3/PL5D)
#FPGA155: TP39.1 (1_1), U1.155 (F2/PL23C)
#FPGA156: TP55.1 (1_1), U1.156 (B2/PL14C)
#LED: CN2.31 (/LED), TP12.1 (1_1)
#PACK: CN2.20 (/PACK), TP9.1 (1_1)
#PBUSY: CN2.18 (PBUSY), TP10.1 (1_1)
#PPD0: CN2.23 (PPD0), TP8.1 (1_1)
#PPD1: CN2.24 (PPD1), TP7.1 (1_1)
#PPD2: CN2.25 (PPD2), TP6.1 (1_1)
#PPD3: CN2.26 (PPD3), TP5.1 (1_1)
#PPD4: CN2.27 (PPD4), TP4.1 (1_1)
#PPD5: CN2.28 (PPD5), TP3.1 (1_1)
#PPD6: CN2.29 (PPD6), TP2.1 (1_1)
#PPD7: CN2.30 (PPD7), TP1.1 (1_1)
#PPOUT: CN2.16 (PPOUT), TP11.1 (1_1)
#SOG: CN2.13 (SOG), TP14.1 (1_1)
#TBASE: CN2.14 (TBASE), TP15.1 (1_1)
#XCLK: CN1.33 (/XCLK), TP17.1 (1_1)
#XCLKEN: CN1.16 (/XCLKEN), TP20.1 (1_1)
/BICK: R7.1, U7.12 (BICK)
/CKS: R10.1, U7.16 (CKS)
/EXT_SWING: R14.2, U5.56 (EXT_SWING)
/GSEL: R11.2, R12.2, U7.7 (GSEL)
/I2CA: R16.1, U5.72 (CI2CA)
/LIN: C19.2, U7.3 (LIN)
/LRCK: R8.1, U7.10 (LRCLK)
/MCLK_OUT: R17.1, U1.154 (A2/PL14A)
/PIXEL_CLK: R18.1, U1.92 (H16/PR8D)
/REGO: C25.1, U7.8 (REGO)
/RIN: C18.2, U7.2 (RIN)
/SD1: U5.40 (SD1)
/SD2: U5.39 (SD2)
/SD3: U5.37 (SD3)
/SDTO: R9.1, U7.9 (SDTO)
/SPDIF: U5.36 (SPDIF)
/VCOM: C24.1, U7.1 (VCOM)
AGA_DETECT: CN2.43 (GND), R58.1, U1.103 (E20/PR17A)
AVCC12: C36.2, C37.2, C38.2, FB2.2, U5.60 (AVCC12), U5.66 (AVCC12_2)
B0: CN2.51 (RGB0), R36.1, U3.30 (4A0)
B0_3V3: U1.59 (R18/PR44B), U3.19 (4Y0)
B0_FPGA: U1.114 (D17/PR2B), U5.32 (D0)
B1: CN2.52 (RGB1), R35.1, U3.29 (4A1)
B1_3V3: U1.57 (T18/PR44D), U3.20 (4Y1)
B1_FPGA: U1.112 (D18/PR5A), U5.31 (D1)
B2: CN2.53 (RGB2), R34.1, U3.27 (4A2)
B2_3V3: U1.51 (C18/PR2A), U3.22 (4Y2)
B2_FPGA: U1.110 (E17/PR5B), U5.30 (D2)
B3: CN2.54 (RGB3), R33.1, U3.26 (4A3)
B3_3V3: U1.49 (K18/PR20D), U3.23 (4Y3)
B3_FPGA: U1.104 (E16/PR2C), U5.29 (D3)
B4: CN1.23 (RGB4), U4.37 (2A3)
B4_3V3: U1.135 (C3/PL8C), U4.12 (2Y3)
B4_FPGA: U1.102 (F16/PR2D), U5.28 (D4)
B5: CN2.10 (RGB5), U3.43 (1A3)
B5_3V3: U1.75 (N17/PR35A), U3.6 (1Y3)
B5_FPGA: U1.100 (F17/PR8A), U5.27 (D5)
B6: CN2.11 (RGB6), U3.41 (2A0)
B6_3V3: U1.73 (P18/PR38D), U3.8 (2Y0)
B6_FPGA: U1.98 (E18/PR5C), U5.25 (D6)
B7: CN1.25 (RGB7), U4.36 (3A0)
B7_3V3: U1.133 (B4/PL5B), U4.13 (3Y0)
B7_FPGA: U1.96 (G16/PR8C), U5.24 (D7)
BCLK: R7.2, U5.45 (SCK)
BT1: D5.2 (A), J4.1, R25.1, R30.2, SW1.2
BT1_INPUT: C45.1, D5.1 (K), R30.1, U1.147 (D2/PL17C)
BT2: D6.2 (A), J4.3, R26.1, R31.2, SW2.2
BT2_INPUT: C46.1, D6.1 (K), R31.1, U1.149 (D1/PL17B)
BT3: D7.2 (A), J4.5, R27.1, R32.2, SW3.2
BT3_INPUT: C47.1, D7.1 (K), R32.1, U1.151 (E2/PL23D)
C28O: CN1.5 (C28O), R1.1
C28O_3V3: U1.91 (J19/PR23A), U4.5 (1Y2)
CEC_A: D2.1 (INPUT_1), D2.10 (NC), J1.13 (CEC), U5.71 (CEC_A)
CEC_D: U1.150 (K5/PL35B), U5.50 (CEC_D)
CK+: D3.5 (INPUT_4), D3.6 (NC), J1.10 (CK+), U5.59 (TXC+)
CK-: D4.1 (INPUT_1), D4.10 (NC), J1.12 (CK-), U5.58 (TXC-)
CSYNC: CN1.14 (/CSYNC), U4.40 (2A1)
CSYNC_3V3: U1.139 (A3/PL5C), U4.9 (2Y1)
CVCC12: C29.2, C30.2, C31.2, C32.2, C33.2, C34.2, FB1.2, U5.5 (CVCC12), U5.12 (CVCC12), U5.26 (CVCC12), U5.42 (CVCC12), U5.47 (CVCC12), U5.53 (CVCC12)
D0+: D3.2 (INPUT_2), D3.9 (NC), J1.7 (D0+), U5.62 (TX0+)
D0-: D3.4 (INPUT_3), D3.7 (NC), J1.9 (D0-), U5.61 (TX0-)
D1+: D2.5 (INPUT_4), D2.6 (NC), J1.4 (D1+), U5.65 (TX1+)
D1-: D3.1 (INPUT_1), D3.10 (NC), J1.6 (D1-), U5.64 (TX1-)
D2+: D2.2 (INPUT_2), D2.9 (NC), J1.1 (D2+), U5.68 (TX2+)
D2-: D2.4 (INPUT_3), D2.7 (NC), J1.3 (D2-), U5.67 (TX2-)
DDC_SCL: D4.2 (INPUT_2), D4.9 (NC), J1.15 (SCL), R20.1, U5.49 (DSCL)
DDC_SDA: D4.4 (INPUT_3), D4.7 (NC), J1.16 (SDA), R19.1, U5.48 (DSDA)
DE: U1.116 (G5/PL20B), U5.33 (DE)
DIF|TDMI: U1.140 (H5/PL20C), U7.14 (DIF/TDMI)
FSEL: U1.136 (H3/PL20D), U7.15 (FSEL)
G0: CN2.47 (RGB8), R40.1, U3.36 (3A0)
G0_3V3: U1.67 (T17/PR47D), U3.13 (3Y0)
G0_FPGA: U1.94 (F18/PR5D), U5.23 (D8)
G1: CN2.48 (RGB9), R39.1, U3.35 (3A1)
G1_3V3: U1.65 (M17/PR32B), U3.14 (3Y1)
G1_FPGA: U1.90 (G18/PR8B), U5.20 (D9)
G2: CN2.49 (RGB10), R38.1, U3.33 (3A2)
G2_3V3: U1.63 (P17/PR32D), U3.16 (3Y2)
G2_FPGA: U1.88 (H17/PR11B), U5.19 (D10)
G3: CN2.50 (RGB11), R37.1, U3.32 (3A3)
G3_3V3: U1.61 (R17/PR35D), U3.17 (3Y3)
G3_FPGA: U1.86 (H18/PR11A), U5.18 (D11)
G4: CN2.6 (RGB12), U3.47 (1A0)
G4_3V3: U1.85 (K20/PR23D), U3.2 (1Y0)
G4_FPGA: U1.84 (J17/PR11C), U5.17 (D12)
G5: CN2.7 (RGB13), U3.44 (1A2)
G5_3V3: U1.77 (N18/PR32C), U3.5 (1Y2)
G5_FPGA: U1.82 (J18/PR20C), U5.16 (D13)
G6: CN2.8 (RGB14), U3.46 (1A1)
G6_3V3: U1.83 (L18/PR29C), U3.3 (1Y1)
G6_FPGA: U1.80 (J16/PR11D), U5.15 (D14)
G7: CN1.27 (RGB15), U4.33 (3A2)
G7_3V3: U1.129 (D3/PL8D), U4.16 (3Y2)
G7_FPGA: U1.78 (P16/PR35B), U5.14 (D15)
GND: C1.1, C2.1, C3.1, C4.1, C5.1, C6.1, C7.1, C8.1, C9.1, C10.1, C11.1, C12.1, C13.1, C14.1, C15.1, C16.1, C17.1, C20.2, C21.2, C22.1, C23.1, C24.2, C25.2, C26.1, C27.1, C28.1, C29.1, C30.1, C31.1, C32.1, C33.1, C34.1, C35.2, C36.1, C37.1, C38.1, C39.1, C40.1, C41.1, C42.1, C43.1, C44.1, C45.2, C46.2, C47.2, C48.1, C49.1, C50.1, C51.1, C52.2, C53.2, C58.1, C59.1, C60.1, C61.2, C62.1, C63.1, C64.1, C65.1, CN1.9 (GND), CN1.12 (GND), CN1.13 (GND), CN1.17 (GND), CN1.20 (GND), CN1.21 (GND), CN1.24 (GND), CN1.32 (GND), CN2.1 (GND), CN2.5 (GND), CN2.9 (GND), CN2.12 (GND), CN2.22 (GND), CN2.32 (GND), CN2.34 (AGND), CN2.36 (AGND), CN2.44 (GND), D1.2 (A), D2.3 (GND), D2.8 (GND), D3.3 (GND), D3.8 (GND), D4.3 (GND), D4.8 (GND), D8.3 (GND), H1.1 (1_1), H2.1 (1_1), J1.2 (D2S), J1.5 (D1S), J1.8 (D0S), J1.11 (CKS), J1.17 (GND), J1.SH, J2.5, J4.2, J4.4, J4.6, J5.1, J6.1 (Sleeve), R11.1, R13.2, R15.1, R16.2, R33.2, R34.2, R35.2, R36.2, R37.2, R38.2, R39.2, R40.2, R41.2, R42.2, R43.2, R44.2, R47.1, R48.1, R56.1, R57.2, R60.2, SW1.1, SW1.3 (GND), SW2.1, SW2.3 (GND), SW3.1, SW3.3 (GND), U1.1 (GND), U1.3 (GND), U1.5 (GND), U1.7 (GND), U1.9 (GND), U1.11 (GND), U1.39 (GND), U1.40 (GND), U1.55 (GND), U1.56 (GND), U1.105 (GND), U1.106 (GND), U1.107 (GND), U1.108 (GND), U1.157 (GND), U1.158 (GND), U1.199 (GND), U1.200 (GND), U1.MP1, U1.MP2, U2.1 (GND), U3.1 (1~OE), U3.4 (GND_1), U3.10 (GND_2), U3.15 (GND_3), U3.21 (GND_4), U3.24 (4~OE), U3.25 (3~OE), U3.28 (GND_5), U3.34 (GND_6), U3.39 (GND_7), U3.45 (GND_8), U3.48 (2~OE), U4.1 (1~OE), U4.4 (GND_1), U4.10 (GND_2), U4.15 (GND_3), U4.21 (GND_4), U4.24 (4~OE), U4.25 (3~OE), U4.28 (GND_5), U4.34 (GND_6), U4.39 (GND_7), U4.45 (GND_8), U4.48 (2~OE), U5.43 (CGND), U5.55 (RSVDL), U5.57 (IOGND), U5.63 (AGND), U5.69 (IO_SEL), U5.70 (VDDQ), U5.73 (TP), U6.3 (GND), U7.4 (VSS), U8.2 (GND), U9.4 (V-), U10.2 (GND), X1.2 (GND), X2.2 (GND)
HDMI_5V: C43.2, C44.2, D1.1 (C), J1.18 (+5V), U10.6 (OUT)
HDMI_EN: R29.1, U1.126 (F4/PL11A), U10.3 (EN)
HDMI_FAULT: R28.1, U1.153 (E1/PL17D), U10.4 (/FAULT)
HDMI_RESET: R23.1, U1.148 (K4/PL35A), U5.51 (RESET#)
HPD: D4.5 (INPUT_4), D4.6 (NC), J1.19 (HPD), R13.1, U5.54 (HPD)
HSYNC: CN1.22 (/HSYNC), U4.38 (2A2)
HSYNC_3V3: U1.137 (E3/PL11B), U4.11 (2Y2)
HSYNC_FPGA: U1.118 (D16/PT58B), U5.34 (HSYNC)
I2S0: R9.2, U5.41 (SD0)
INT: R24.1, U1.146 (K3/PL29D), U5.52 (INT)
IOVCC: C40.2, C41.2, C42.2, FB3.2, U5.3 (IOVCC), U5.21 (IOVCC), U5.46 (IOVCC)
LRCLK: R8.2, U5.44 (WS)
L_AUDIO: CN1.3 (LINELF), SJ1.1 (A)
L_AUDMIX: C19.1, R49.2, U9.7
MCLK: R17.2, U5.38 (MCLK), U7.11 (MCLK)
unnamed: C15.2, R3.2, U6.2
unnamed: C54.2, R50.1
unnamed: C55.2, R51.1
unnamed: C56.2, R53.1
unnamed: C57.2, R54.1
unnamed: C60.2, F2.1, FB4.1
unnamed: C52.1, D8.1 (D+), J6.2 (Tip), R45.2, R47.2
unnamed: C53.1, D8.2 (D-), J6.3 (Ring), R46.1, R48.2
unnamed: FB4.2, R59.2
unnamed: R4.1, U6.4
unnamed: R14.1, R15.2
unnamed: C54.1, SJ1.2 (C)
unnamed: C56.1, SJ2.2 (C)
unnamed: R2.2, U3.40 (2A1)
unnamed: R1.2, U4.44 (1A2)
unnamed: C28.2, C35.1, FB1.1, FB2.1, U8.5 (VOUT)
unnamed: R52.1, R53.2, R54.2, U9.2 (-)
unnamed: R49.1, R50.2, R51.2, U9.6 (-)
unnamed: R57.1, U10.5 (ILIM)
unnamed: R5.1, X1.3 (OUT)
unnamed: R6.1, X2.3 (OUT)
PCLK: R18.2, U5.22 (IDCK)
PDN_RESET_N: U1.144 (J5/PL29B), U7.13 (~PDN)
PIXELSW: CN1.30 (/PIXELSW), U4.30 (4A0)
PIXELSW_3V3: U1.125 (C17/PT60B), U4.19 (4Y0)
PSEL: CN2.21 (PSEL), U4.41 (2A0)
PSEL_3V3: U1.141 (C2/PL14D), U4.8 (2Y0)
R0: CN1.1 (RGB16), R44.1, U4.47 (1A0)
R0_3V3: U1.145 (C1/PL17A), U4.2 (1Y0)
R0_FPGA: U1.76 (L5/PL35D), U5.13 (D16)
R1: CN1.2 (RGB17), R43.1, U4.46 (1A1)
R1_3V3: U1.143 (B1/PL14B), U4.3 (1Y1)
R1_FPGA: U1.74 (L4/PL35C), U5.11 (D17)
R2: CN2.45 (RGB18), R42.1, U3.38 (2A2)
R2_3V3: U1.71 (U17/PR47B), U3.11 (2Y2)
R2_FPGA: U1.72 (M4/PL38A), U5.10 (D18)
R3: CN2.46 (RGB19), R41.1, U3.37 (2A3)
R3_3V3: U1.69 (U18/PR47A), U3.12 (2Y3)
R3_FPGA: U1.70 (N4/PL38C), U5.9 (D19)
R4: CN2.2 (RGB20), U4.29 (4A1)
R4_3V3: U1.123 (A19/PT67A), U4.20 (4Y1)
R4_FPGA: U1.68 (R3/PB15B), U5.8 (D20)
R5: CN2.3 (RGB21), U4.27 (4A2)
R5_3V3: U1.121 (B18/PT62B), U4.22 (4Y2)
R5_FPGA: U1.66 (T3/PB18A), U5.7 (D21)
R6: CN2.4 (RGB22), U4.26 (4A3)
R6_3V3: U1.119 (B19/PT65B), U4.23 (4Y3)
R6_FPGA: U1.64 (M3/PL41B), U5.6 (D22)
R7: CN1.29 (RGB23), U4.32 (3A3)
R7_3V3: U1.127 (A18/PT65A), U4.17 (3Y3)
R7_FPGA: U1.62 (T2/PB13A), U5.4 (D23)
RAWLF: CN2.33 (RAWLF), SJ1.3 (B)
RAWRT: CN2.35 (RAWRT), SJ2.3 (B)
R_AUDIO: CN1.4 (LINERT), SJ2.1 (A)
R_AUDMIX: C18.1, R52.2, U9.1
SCL_I2C: R21.1, U1.58 (N2/PL44A), U5.1 (CSCL)
SDA_I2C: R22.1, U1.60 (N3/PL41A), U5.2 (CSDA)
SPARE_IN5: R60.1, TP24.1 (1_1), U4.43 (1A3)
SPARE_OUT3: TP25.1 (1_1), U4.6 (1Y3)
TCK: J2.4, J3.1
TDI: J2.2, J3.3
TDO: J2.3, J3.4
TMS: J2.1, J3.2
VA: C61.1, C62.2, C63.2, C64.2, R55.2, R59.1, U9.8 (V+)
VBIAS: C58.2, C59.2, R55.1, R56.2, U9.3 (+), U9.5 (+)
VCC: C1.2, C2.2, C3.2, C4.2, C20.1, C21.1, C48.2, C49.2, C50.2, C51.2, C65.2, F1.2, R10.2, R19.2, R20.2, U1.2 (5V), U1.4 (5V), U1.6 (5V), U1.8 (5V), U1.10 (5V), U1.12 (5V), U2.3 (VI), U7.5 (VA), U10.1 (IN)
VCDAC: CN2.15 (VCDAC), R2.1
VCDAC_3V3: R3.1, U3.9 (2Y1), U6.1
VSYNC: CN1.26 (/VSYNC), U4.35 (3A1)
VSYNC_3V3: U1.131 (C4/PL5A), U4.14 (3Y1)
VSYNC_FPGA: U1.120 (F5/PL11D), U5.35 (VSYNC)
XAUDESDL: J5.3, J6.4 (Tip_Switch)
XAUDESDR: J5.2, J6.5 (Ring_Switch)
XAUDL: C55.1, R45.1
XAUDR: C57.1, R46.2
XTAL_24.576M: R6.2, U1.89 (J20/PR23C)
XTAL_27M: R5.2, U1.134 (G3/PL23A)

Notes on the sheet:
X7R
ESD Protection
Analog audio input from CDDA or other internal source
Test Points for Unused Pins
RGB Inputs 0-7 Blue 0-7 8-15 Green 0-7 16-23 Red 0-7
Pull downs for OCS/ECS machines

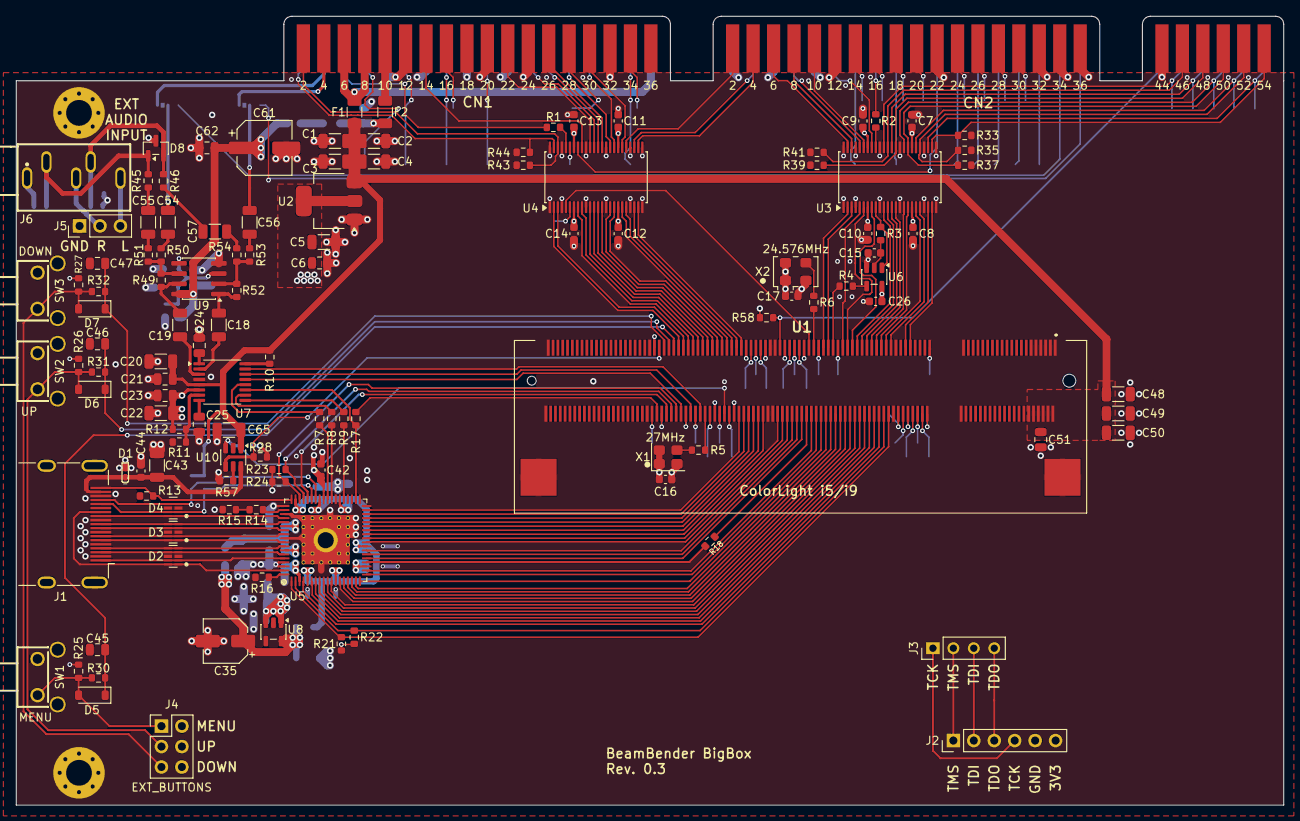
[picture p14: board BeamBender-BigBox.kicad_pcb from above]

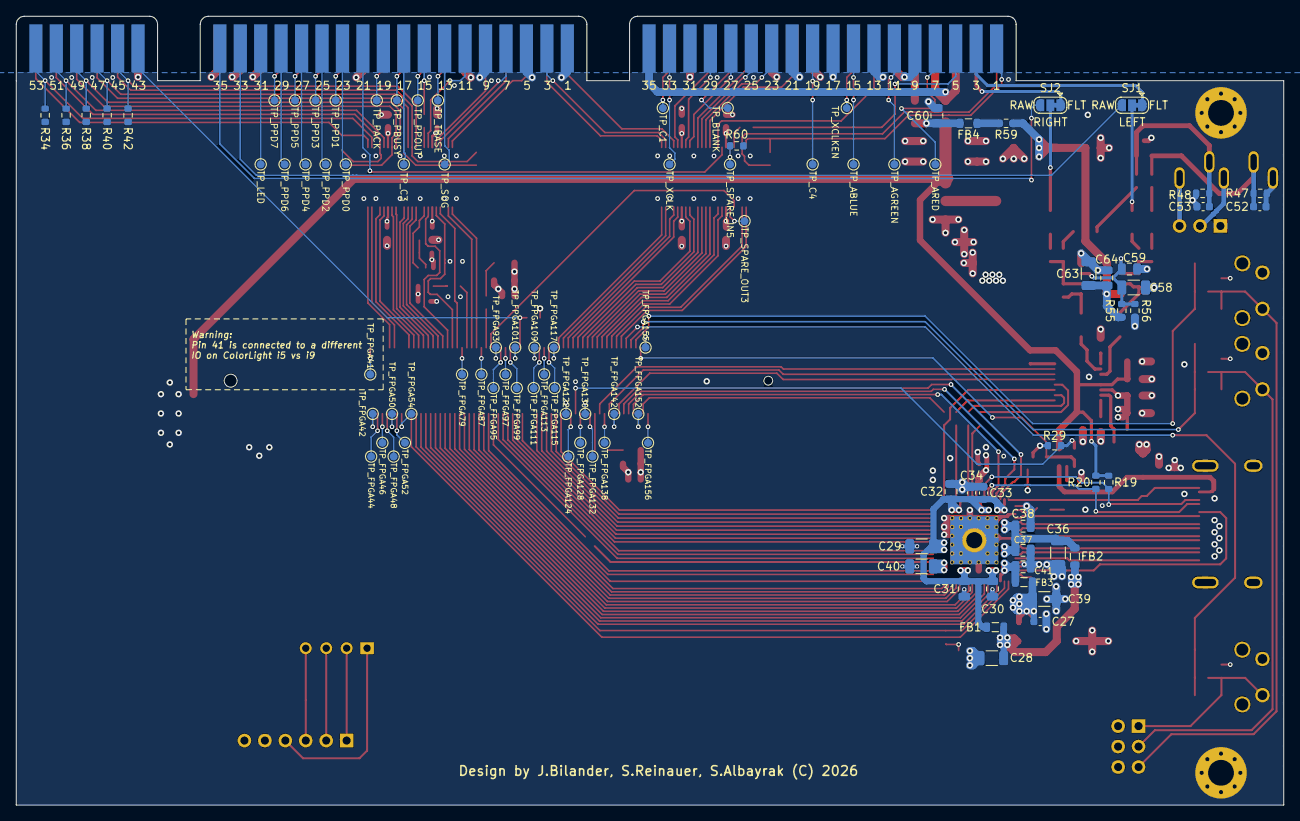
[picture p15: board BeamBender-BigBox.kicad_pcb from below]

Board: 4 copper layers, 157.5 x 98.0 mm, 221 parts (96 on the bottom side), 240 nets.

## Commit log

2026-08-17 BeamBender BigBox
    [BeamBender-BigBox.kicad_pcb, BeamBender-BigBox.kicad_sch, D5V0F4U10LP-7.stp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]
2026-08-17 Created pin assignments in VHDL and Verilog
2026-08-17 Add R0/R1 pull down resistors
    [BeamBender-BigBox.kicad_pcb, BeamBender-BigBox.kicad_sch]
2026-08-18 Add EXT audio input mixed with Paula audio
    External audio input via 3.5mm jack with an alternative 3 pin internal header mixed with Paula audio via OPA1692.
    [BeamBender-BigBox.kicad_pcb, BeamBender-BigBox.kicad_sch, SJ1-3535NG.stp]
2026-08-19 Add HDMI back-feed protection
    [BeamBender-BigBox.kicad_pcb, BeamBender-BigBox.kicad_sch]
2026-08-25 Rev 0.3
    Added test points for unused AV slot and FPGA pins
    Added option to use Paula RAW audio
    [BeamBender-BigBox.kicad_pcb, BeamBender-BigBox.kicad_sch, corrections.csv]
2026-09-20 Firmware support for adaptive deinterlacing
    [ADV7xx_Limit_MCLK_Output_Frequency.xlsx]
2026-09-23 FW 2026-09-22.03
    Improved adaptive deinterlacing
    BBKeyCon app
    [FPGA-SC-02033-2-0-ECP5U-25-Pinout.xlsx]
2026-10-29 Upload new firmware and docs
    ### Firmware (2026-09-30.07 to 2026-10-28.04)
    - Six new output formats: 640x480, 1280x800, 1280x960, 1440x900, 1600x900 and 1680x1050 (fourteen in all)
    - Monitor Modes page: the formats the monitor's EDID lists, at 50 and 60 Hz
    - Gamma setting, 0.42 to 2.38, shown as a bar
    - Pixel Smoothing: Off, Soft, Softer, Softest
    - Separate scale settings for interlaced screens
    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
2026-10-31 Firmware 2026-10-30.03, BBLink 1.30, rev 0.3 production files and docs updates
    Firmware (Firmware/: 2026-10-30.03 for the i9 and i5, standard and -c28, in place of 2026-10-28.04)
    - Capture Clock on Display Info is steady: measured over 64 ms and shown to the nearest kHz, so it no longer flickers between two values.
    - The input Frame Rate is timed against the card's own 27 MHz clock and holds steady (a PAL screen no longer flips between 49.91 and 49.92 Hz).
    - The output frame rate is rounded like the input's: both read 50.38 Hz for a PAL screen on an NTSC-crystal machine with the -c28 firmware.
    - Capture Width goes up to 800 and is shown in the screen's own pixels (up to 1360 on a Super-Hires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

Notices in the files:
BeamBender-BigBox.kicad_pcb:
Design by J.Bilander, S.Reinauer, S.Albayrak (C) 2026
